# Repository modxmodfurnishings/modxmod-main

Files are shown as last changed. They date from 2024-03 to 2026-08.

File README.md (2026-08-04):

# MODxMOD Main Project

## Rationale

Furniture and devices should adapt to people, not the other way around.

MODxMOD FURNISHINGS strives to create an open system (the Open Furnishings System) of integration between hardware-to-hardware components, as well as hardware-to-software and software-to-software components.  As an organization, we will provide these components and specifications, but the open source nature of this project allows anyone to build upon and adapt the technology and plans to their personal needs.

In short: everyone can be a creator, everyone can interoperate, and no one organization will own the interoperation technology.

See the in-depth [rationale explanation](./docs/rationale.md).

## System Parts

The Open Furnishings System describes several pieces:

- Naming and templates for parts
- Naming and templates interfaces
- Naming and workflows for interactions
- Templates for various solutions

## Designs that change

Designs in this repository are subject to change, especially those in the Labs folder.

## License

modxmod-main by MODxMOD FURNISHINGS is marked with CC0 1.0.
To view a copy of this license, visit http://creativecommons.org/publicdomain/zero/1.0

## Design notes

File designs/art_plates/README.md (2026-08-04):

# Art Plates

User-swappable exterior art is one of the core goals of MODxMOD FURNISHINGS products. Different specifications ensure the best fit for your art pieces. This document describes art plates compatible with the [Mod Block](../mod_block/).

Our goal is to encourage user-created art, so here are specifications for making your own! See some cool [examples](#examples) below.

## How to use this document

This document provides details on terminology and dimensional specifications. It will also point you to resources. Most units are in metric, and Imperial equivalents are shown where possible. ***Note: Imperial units may be rounded down to the nearest fraction.***

## Quick start

The fastest way to start is to:

- 3D print using the `.STEP` file, or
- Laser cut using the `.DXF` file

Be sure to use one 1/4" material or two 1/8" materials.

## AP102 (Version 1.0)

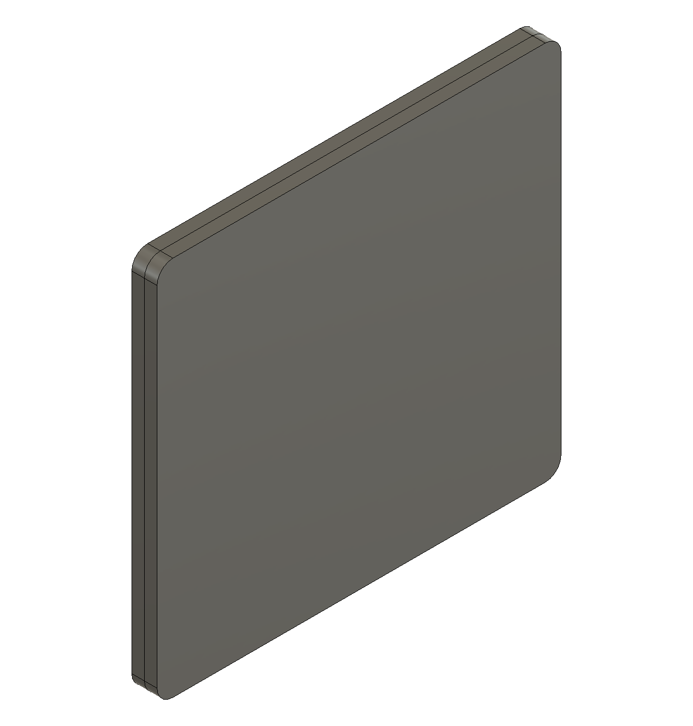
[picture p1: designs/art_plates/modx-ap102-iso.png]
AP102 isometric drawing


Starting with the [Mod Block](../mod_block/) product, you can create front art plates that slide into the provided slots. In general, your design should be slightly smaller than a 4" coaster.

### Viewable area

Because the art plates rest inside a 6mm-deep slot, the visible area is actually 90x90mm (3.5x3.5").

It is also best to leave a bit of padding around the design, perhaps 10mm (3/8").

### Maximum Dimensions

The maximum dimensions are:

- 102mm wide, 102mm tall, 6.5mm thick
- 4" wide, 4" tall, 1/4" thick

The slot it fits into is machined to:

- 103mm wide, 103mm tall, 7mm deep

You *must allow* for a small amount of wiggle room, hence the *102mm maximum dimension*:

- Wood may change shape
- The plates must slide in/out easily, and
- There are machining inconsistencies

The thickness is designed to easily accommodate one 1/4" sheet of plywood or two 1/8" sheets of plywood. Laser-safe acrylic often comes in similar thicknesses.

The 102x102mm dimension is also approximately the same as a standard 4" coaster.

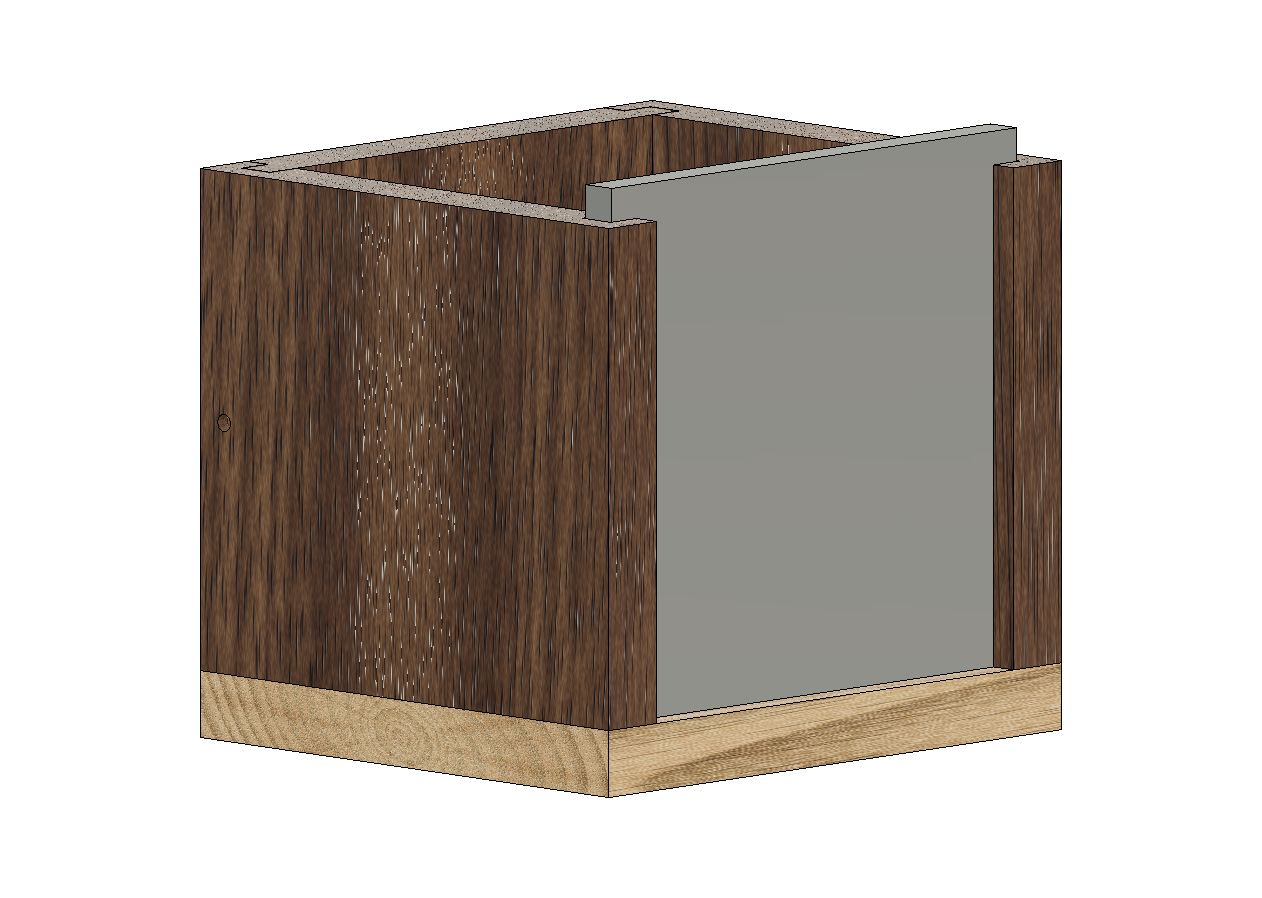
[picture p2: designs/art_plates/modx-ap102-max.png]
Drawing of art plate exceeding the top of the Mod Block


If you create the maximum 102x102 size, it ***will*** protrude over the top of the [Mod Block](../mod_block/). This is fine because the box's cap has a recessed slot. However, for designs meant to be used without the box cap, you should use the "short" height.

### Short Dimensions

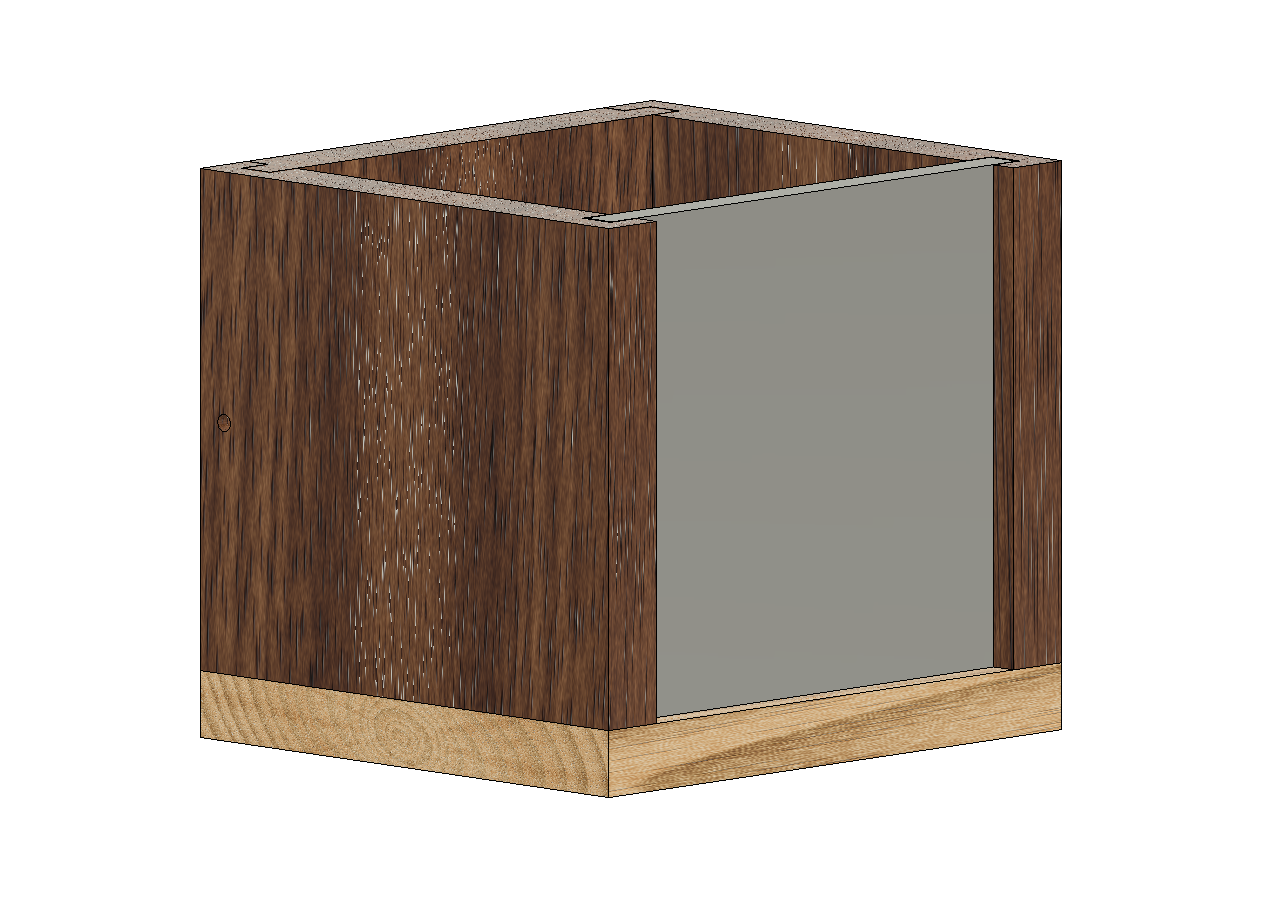
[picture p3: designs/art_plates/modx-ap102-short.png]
Drawing of art plate exceeding the top of the Mod Block


The recommended dimensions for open-box designs are:

- 102mm wide, 96mm tall, 6.5mm thick
- 4" wide, 3.75" tall, 1/4" thick

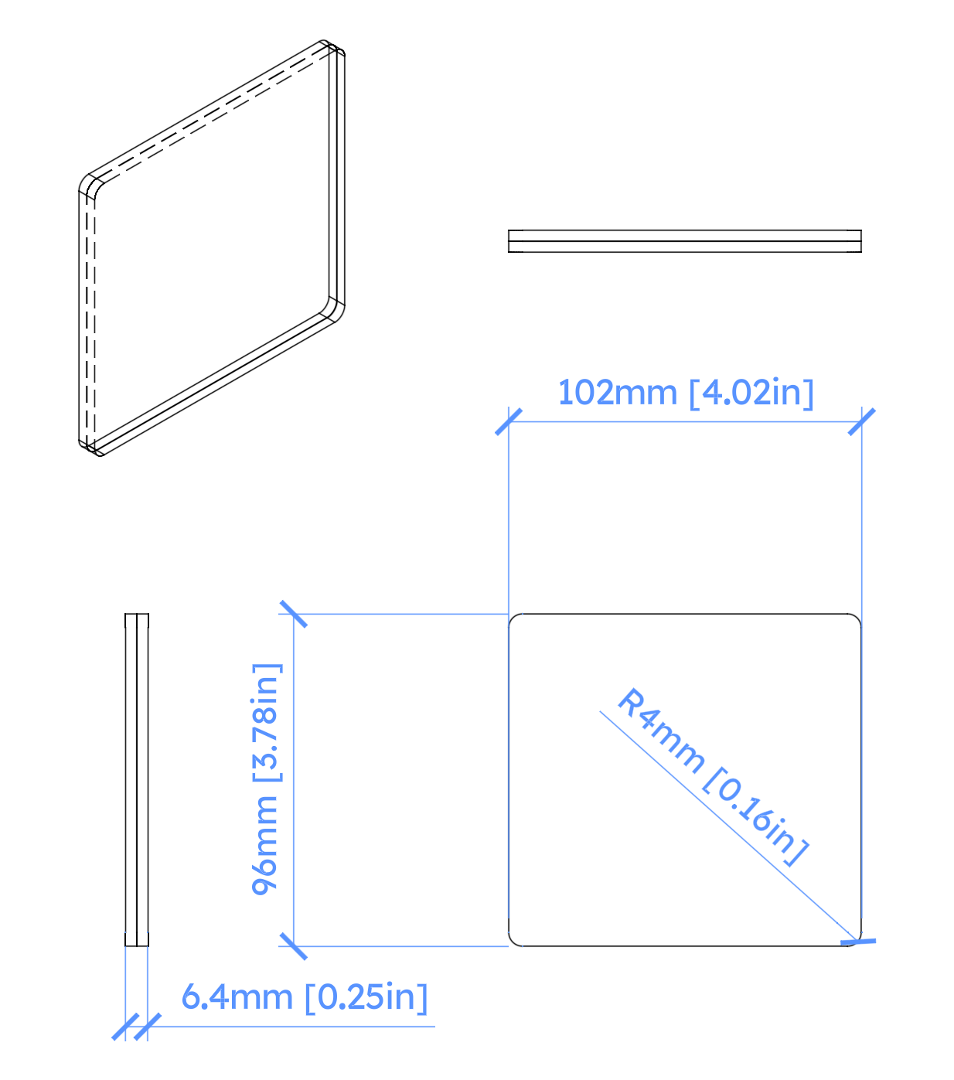
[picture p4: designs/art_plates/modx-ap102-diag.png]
Diagram of AP102 short


### Recommendations

- **Round off the corners about 4mm.** The slots the art plates sit in may not be perfectly machined.
- **Use calipers.** Ensure the total thickness of the materials doesn't exceed 6.5mm.
- **Use quality materials.** Ensure the materials are clean and smooth. Plywood is very stable. 3D prints are stable if the bed adhesion was good.
- **Create centered short designs:**
  - First design for the maximum 102x102mm dimension
  - Remove the top 6mm of the design, leaving 102x96mm
- The viewable area of the installed art plate is 90x90mm (3.5x3.5"):
  - Repeating patterns should extend the full 102x96mm so they disappear into the slots.
  - Centered designs look best when they have some visual padding. The recommended centered design in the art plate is 74x74mm (2-7/8" square).

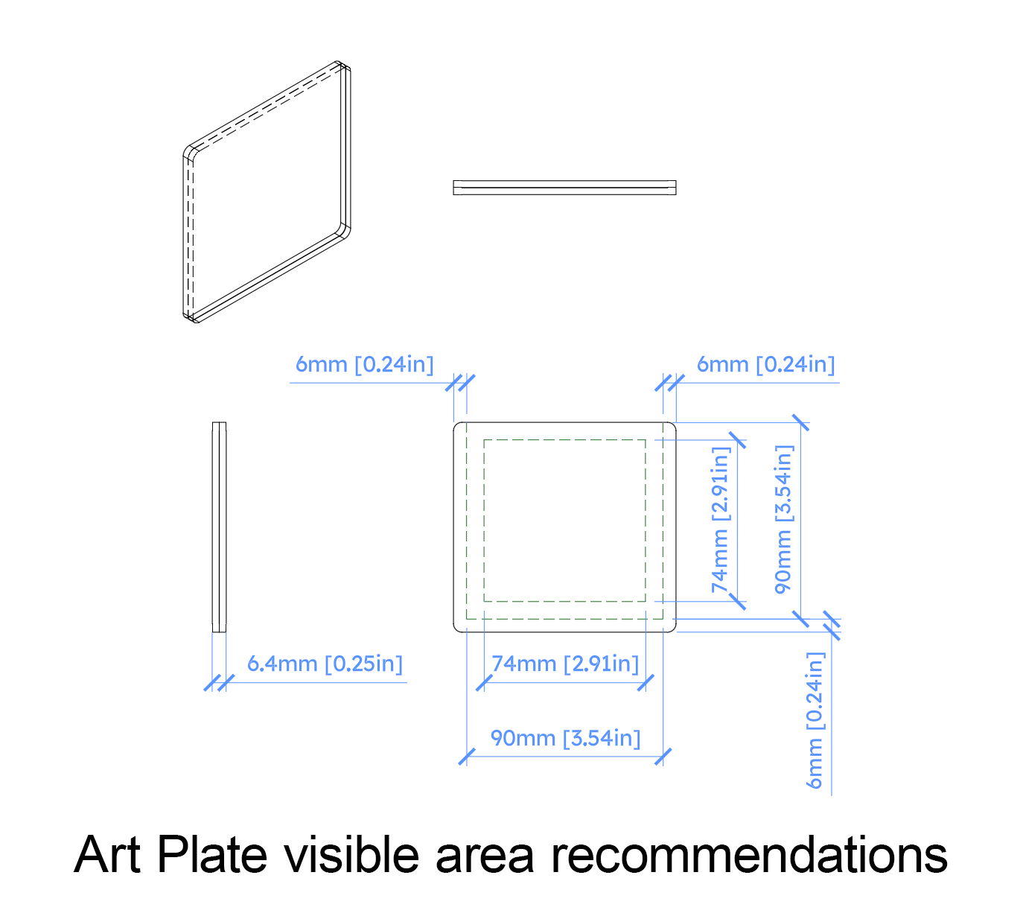
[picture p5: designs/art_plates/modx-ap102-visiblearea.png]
Diagram of recommended visible area


## Examples

### Solid front example

Use the `AP102-14inch.step` or `modx-ap102-short.dxf` files to cut out 1/4" material (or two 1/8" materials).

### Semi-open design example

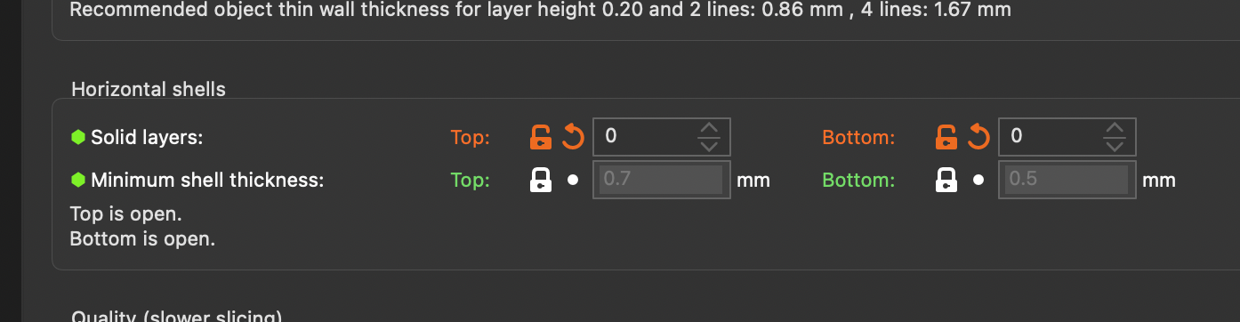
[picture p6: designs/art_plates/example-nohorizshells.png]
Screen shot of slicer configuration


In your 3D printer slicer software, import the `.STEP` model and ***don't print*** the top and bottom "horizontal shells". This will expose the infill pattern, and you can get some very nice effects.

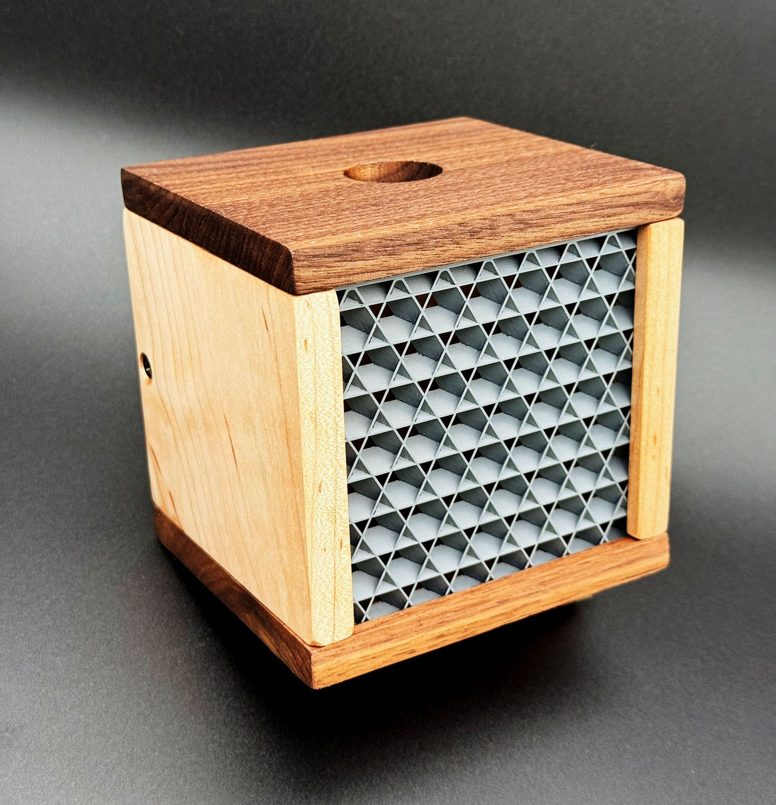
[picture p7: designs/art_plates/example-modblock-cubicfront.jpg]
Photo of 3D printed art plate


### Offset layered design

By cutting two 1/8" plates where the rear plate has slightly smaller holes, you get a layered dimensional design:

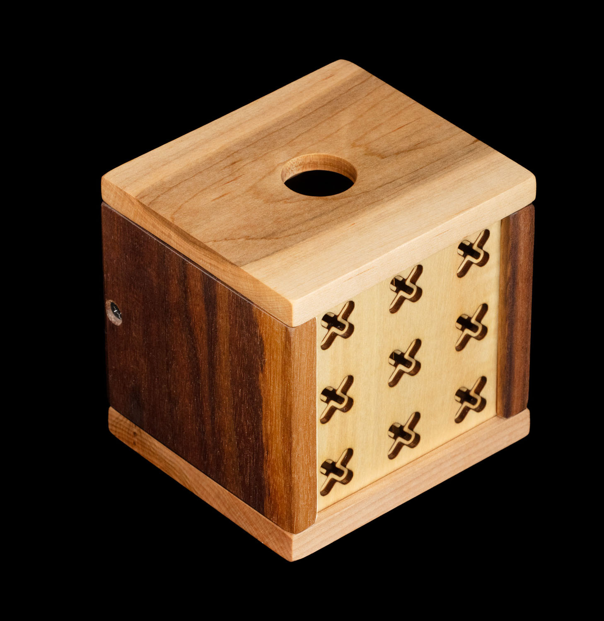
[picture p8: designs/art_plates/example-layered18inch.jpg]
Photo of two layered art plates


## Resources

- [Art Plate models](./models/)
- [Mod Block models](../mod_block/models/)

## Copyright and license

This file and all other files in this repository are marked with CC0 1.0. To view a copy of this license, visit http://creativecommons.org/publicdomain/zero/1.0

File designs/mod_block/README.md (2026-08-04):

# Mod Block

Mod Block with X Marks design front

The Mod Block is intended to be a transformable container. The main features:

- Footprint is 114mm wide by 102mm deep (4.5" wide x 4" deep)
- 12mm thick walls
- Screws-only assembly, no glued walls, no unfinished surfaces
- Symmetric wall 6mm-deep 7mm-wide slots, floor and lid 6mm-deep slots (1/4"), fits a standard 4" coaster
- Standard 1" rear hole, shipped with a 1" press fit 3D printed plug
- 90x90mm viewable area (3.5x3.5")

In the current shipping state as of July 2026:

- Floor secures the walls with screws
- Rear wall screwed in
- Press fit lid with 8mm interior protrusion, 1" finger hole
- User-swappable front plates

## Dimensions with lid on

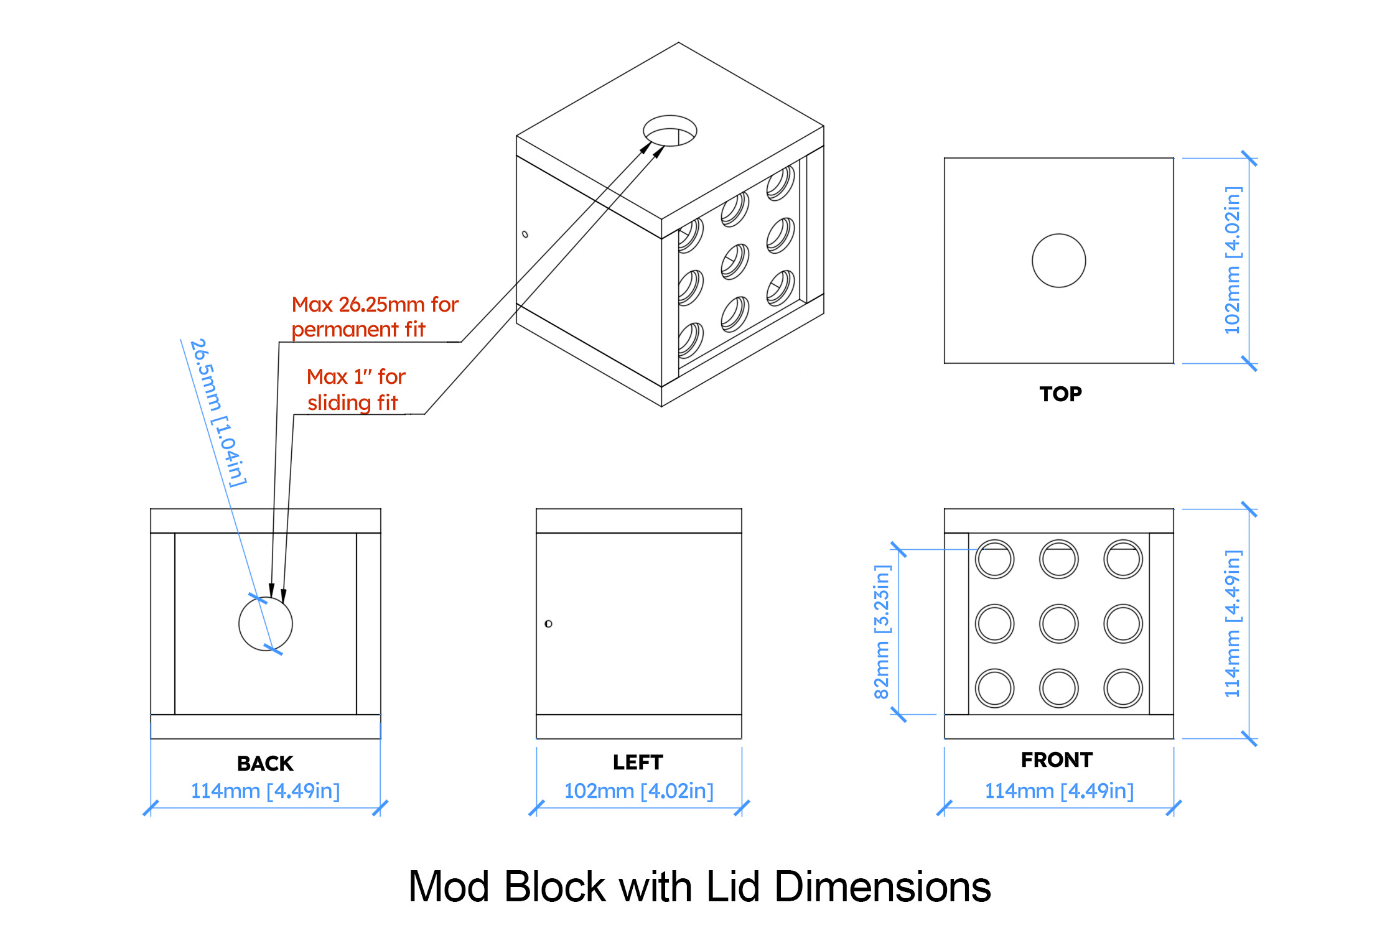
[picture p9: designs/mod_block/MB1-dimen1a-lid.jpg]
Diagram of Mod Block with lid


The current version with lid on measures:

- 114mm wide, 102mm deep, 114mm tall
- 4.5" wide, 4" deep, 4.5" tall

When the front is viewed straight-on, it looks like a square block with a 90mm x 90mm design area (3.5" x 3.5"). The front panel can be swapped with different designs or removed for open access.

*Note: The press fit lid reduces the inner height by 8mm; you should consider 2mm extra padding.*

The effective interior volume is:

- 90mm wide x 78mm deep x 80mm tall
- 3.5" wide x 3" deep x 3.125" tall

## Dimensions with lid off

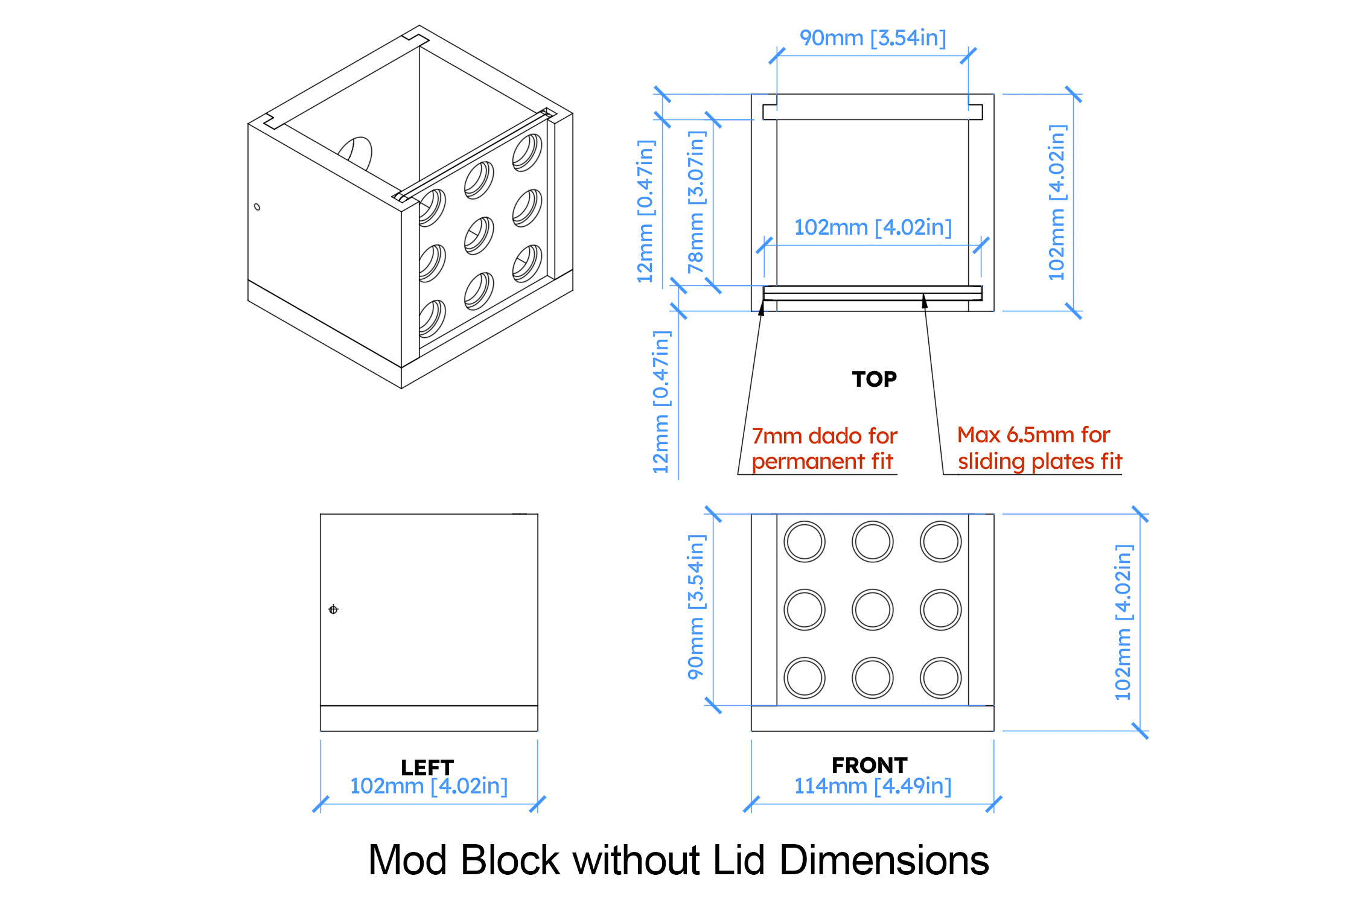
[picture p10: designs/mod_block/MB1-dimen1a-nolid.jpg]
Diagram of Mod Block without lid


With the lid off, the Mod Block is 12mm shorter:

- 114mm wide, 102mm deep, 102mm tall
- 4.5" wide, 4" deep, 4.5" tall

But the interior volume is greater:

- 90mm wide x 78mm deep x 90mm tall
- 3.5" wide x 3" deep x 3.5" tall

*If you remove the front art plate, the interior volume can accomodate a 3.5" notepad cube.*

## Rear/top hole Mod Plug

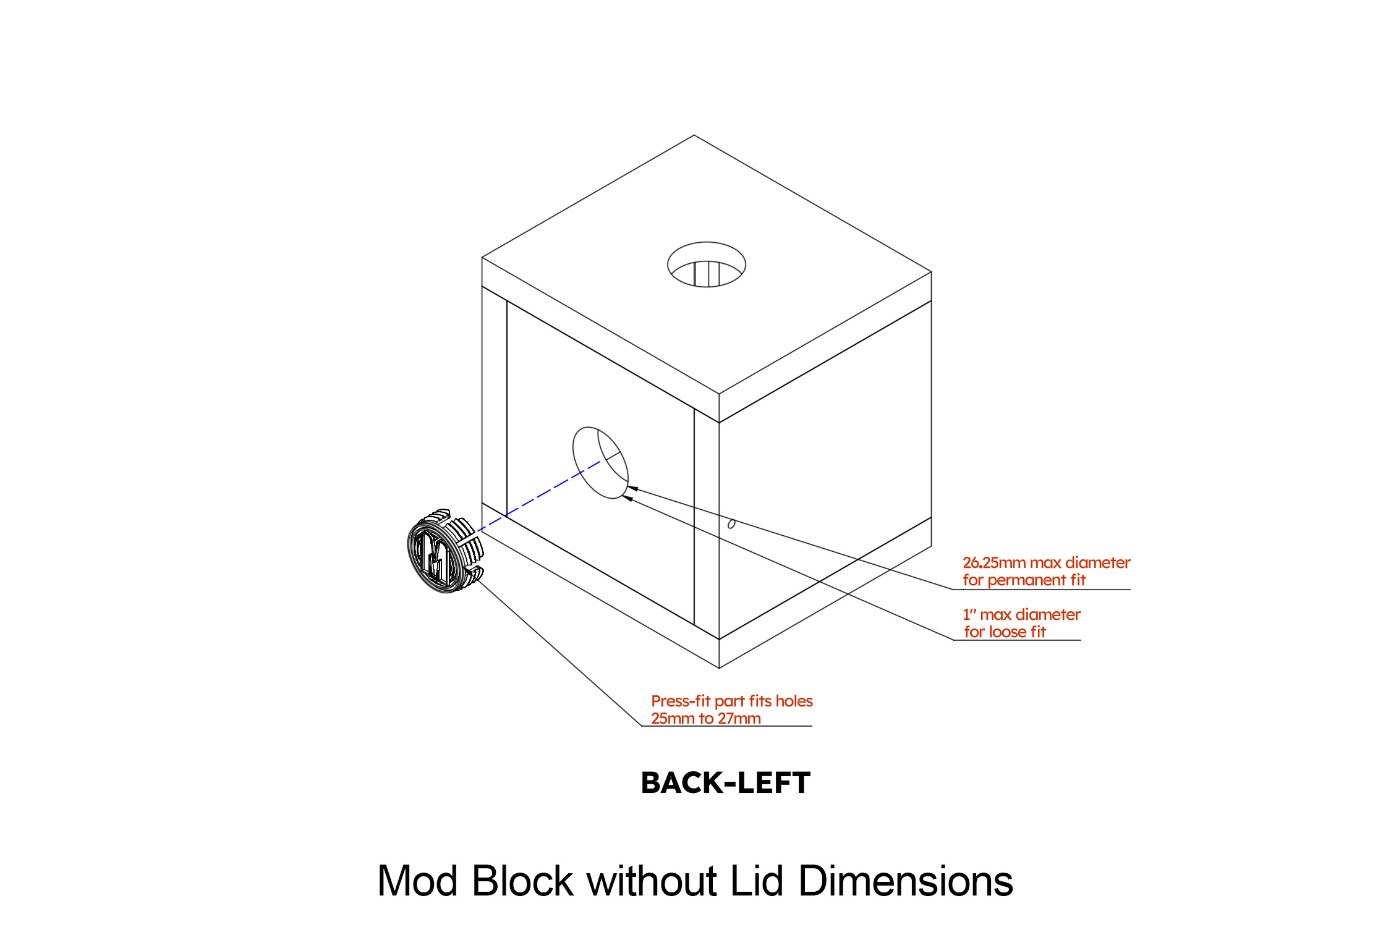
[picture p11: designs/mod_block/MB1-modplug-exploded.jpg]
Mod Plug location diagram


The shipping Mod Block has two 1" openings (machined to 26.5mm), the rear hole is covered with a Mod Plug. The rear hole may change diameter slightly over time due to humidity and material changes.

The Mod Plug or another accessory should adhere to these two diameters:

- 25.4mm (1") for a loose fit. Perfect for dowels or rotating parts.
- 26.25mm for a permanent fit. These parts will likely become difficult to remove; in very dry weather this may become a loose fit.
- 10.5mm is optimal thickness

The shipping Mod Plug has flexible arms which allow it to accommodate holes from 25mm to 27mm. See the [mod_plug](../mod_plug/README.md) directory for specifications.

Permanent installation of a part in the rear or top hole should be done with screws and/or glue. This is especially important if it will be modified.

The Mod Plug design also permits 1/8" material to be slotted into it. See the next section.

## Removable divider panels

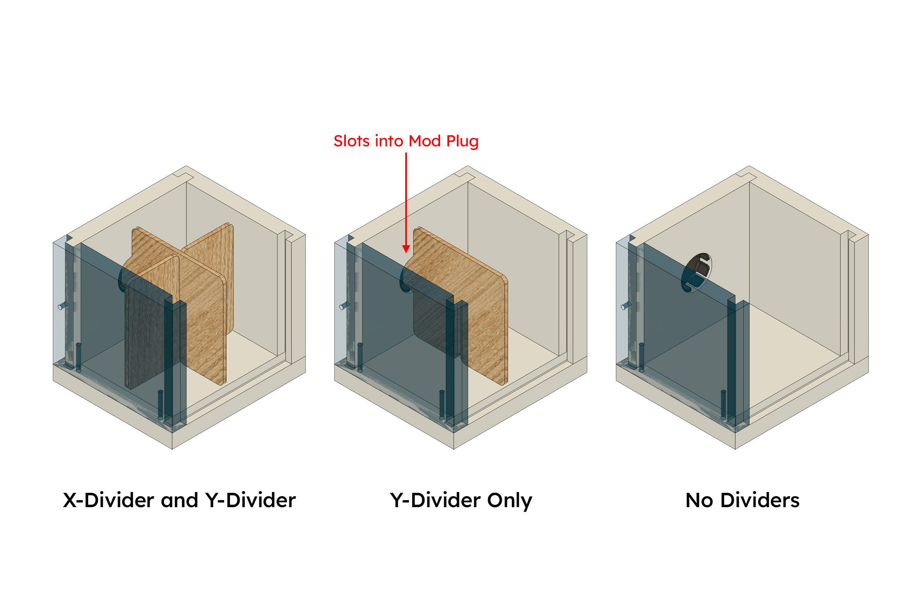
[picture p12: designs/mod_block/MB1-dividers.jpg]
Removable internal dividers diagram


The Mod Block ships with 1/8" dividers that have an interlocking slot in their center. The Y-Divider (that goes from front to back) and an X-Divider (that goes from left to right). The Y-Divider has a key that fits into the Mod Plug in the rear wall to keep it vertically aligned. This configuration creates 4 chambers in the Mod Block.

By removing the X-Divider, the Mod Block has 2 chambers. And by removing all of the dividers it is an open box.

You can design new dividers or inserts. The recommended material is 1/8" thick (approximately 3mm thick) because that will fit into the Mod Plug. But you could design new shapes and even a new Mod Plug (or no plug) as it suits your design goals.

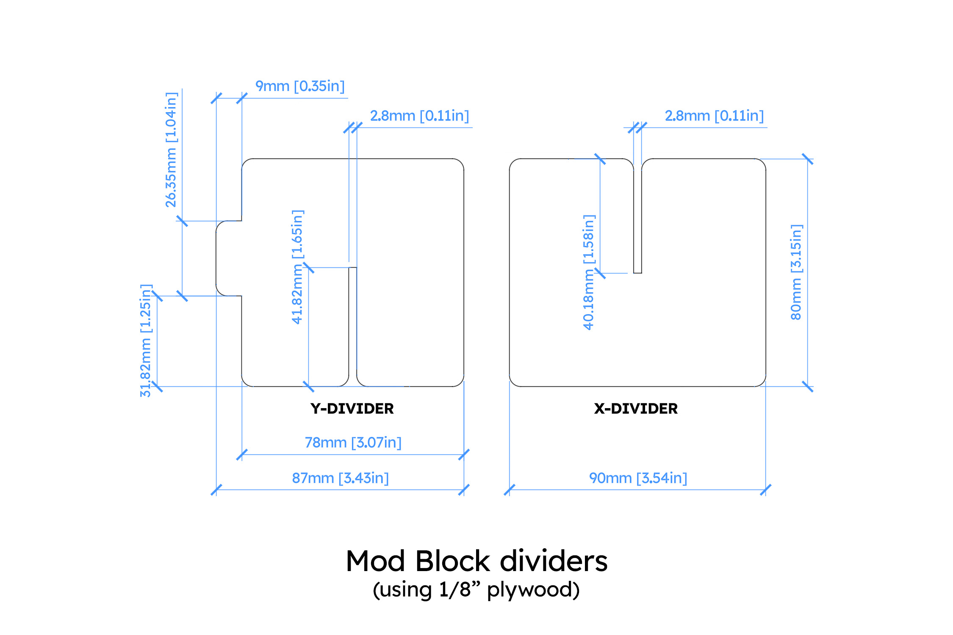
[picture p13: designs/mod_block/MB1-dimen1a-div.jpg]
Diagram of the Y-Divider and X-Divider


## Swappable Art Plates

The front 7mm slots are identical to the rear 7mm slots. In the shipping Mod Block, the front slots have a user-changeable design. 

For more details, please see the [Art Plates](../art_plates/) documentation.

## Resources

- [Mod Block models](./models/)
- [Art Plate models](../art_plates/models/)

## Copyright and license

This file and all other files in this repository are marked with CC0 1.0. To view a copy of this license, visit http://creativecommons.org/publicdomain/zero/1.0

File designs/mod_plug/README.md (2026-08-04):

# Mod Plug

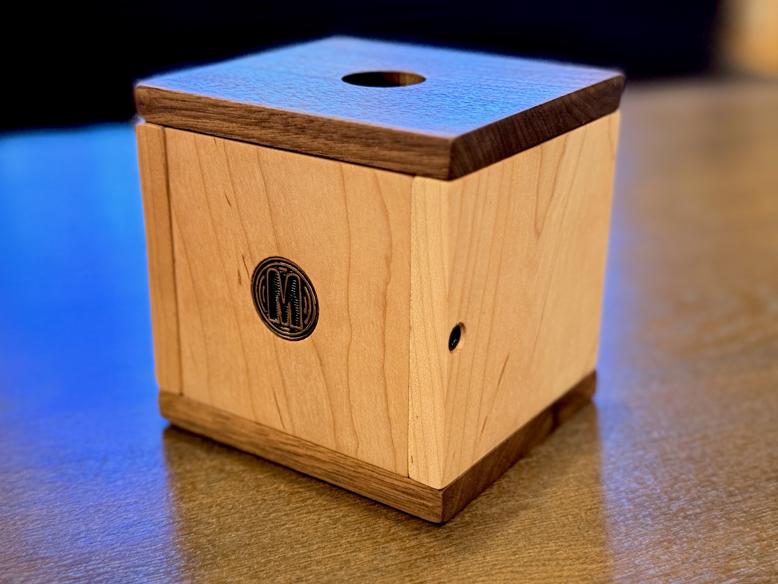
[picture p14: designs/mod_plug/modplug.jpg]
Mod Plug with gold logo, installed


The Mod Plug is a press fit part designed to block the rear hole in a [Mod Block](../mod_block/README.md). It can be permanently installed if desired.

## Mod Plug specifications

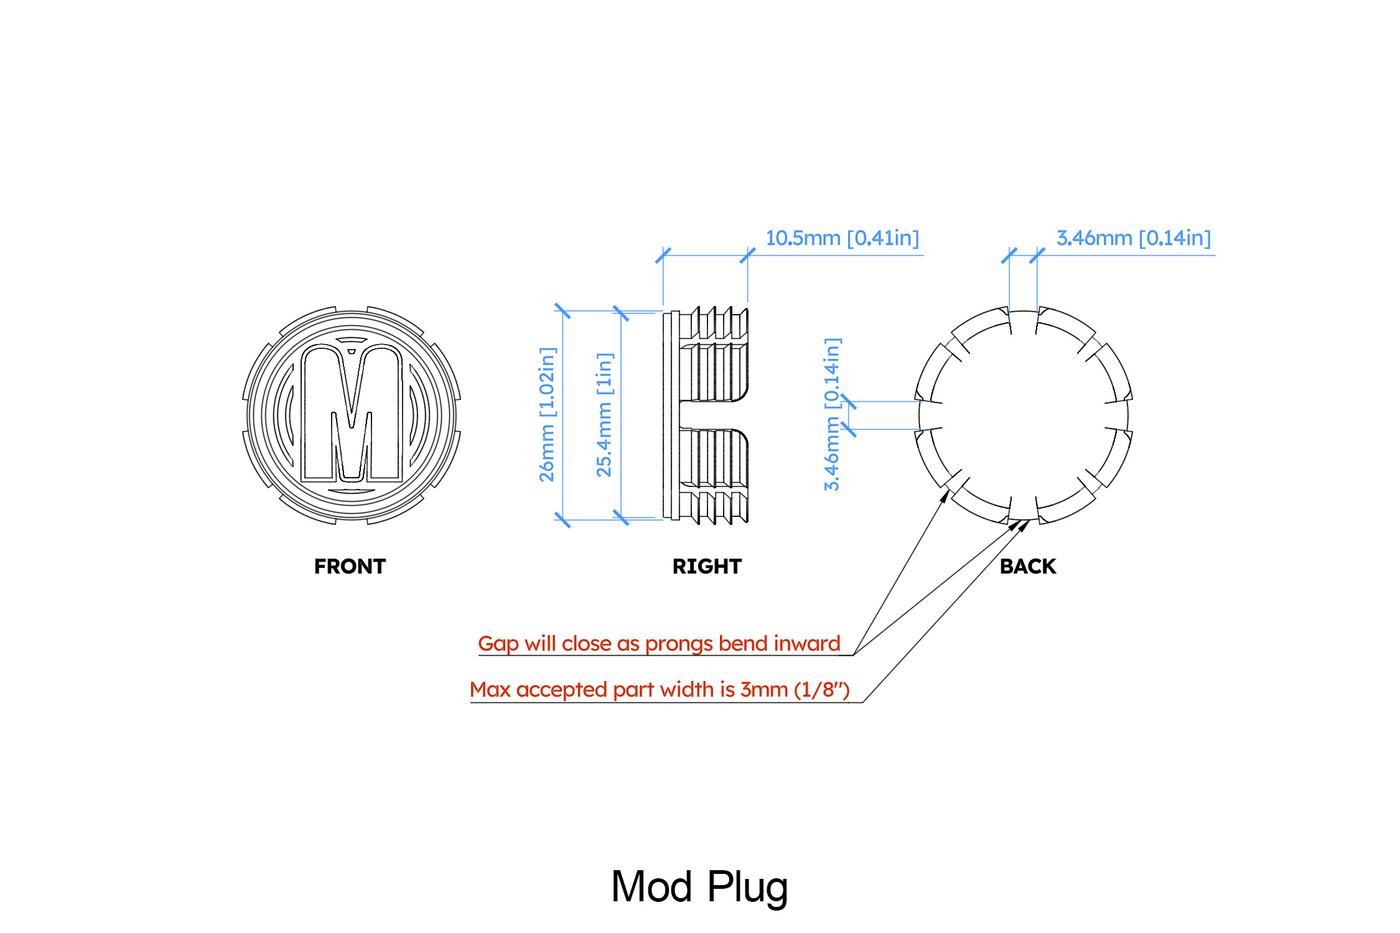
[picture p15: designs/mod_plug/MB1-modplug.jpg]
Diagram of Mod Plug


The provided Mod Plug is a 3D printed part which has flexible arms that should accommodate hole sizes from 25.0mm to 27.0mm. To permanently secure the Mod Plug you should use an adhesive such as epoxy glue or screw the plug into the back wall material.

- No support material required
- PTEG or ABS filament will be stronger, PLA will be more flexible
- Production part uses 0.4mm extruder nozzle
- First bed layers should be 0.5mm, print "logo side" down on bed

## Copyright and license

This file and all other files in this repository are marked with CC0 1.0. To view a copy of this license, visit http://creativecommons.org/publicdomain/zero/1.0

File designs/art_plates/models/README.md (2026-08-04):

# Art Plates models

The purpose of supplying these models is to assist in providing reference assemblies. They are exported in two different formats:

- `.step` meshes exported directly from CAD, and
- `.stl` models processed through a slicer

See also the [Mod Block models](../../mod_block/models/README.md).

## Rationale

By providing models of the 102x96mm Art Plates, artists can install their own designs into Mod Blocks. Product designers may also adapt Art Plates to provide interesting apertures or devices.

As discussed in the [Art Plates README](../README.md), 102mm is effectively a 4" width which is common in square coasters. The 96mm height is preferred because with the box cap removed the top of the art will sit flush with the top edge of the Mod Block.

You may simply design using 4" square coasters, realizing a small top portion of the design will be tucked into the cap.

## File descriptions

The main source files are:

| Filename | Type | Description |
|---|---|---|
| AP102-14inch.step | STEP | Assembled Art Plates as one 1/4" part. |

These have been converted into flattened models:

| Filename | Type | Description |
|---|---|---|
| AP102-14inch.stl | STL  | Assembled 1/4" Art Plate. |
| AP102-2x18inch.stl | STL  | Separated 1/8" Art Plates in 2 parts. |

## Recommended use

### 3D printed Art Plates

3D printing is one of the easiest ways to produce the Art Plates.

Printing a full 1/4" plate will allow you to create some interesting fill patterns. See the [Art Plate examples](../README.md).

### CNC milled Art Plates

It is possible to mill out a relief design. The edges of your Art Plate should be no thicker than 6.5mm, meaning the central part of your design could project forward beyond the front of the Mod Block when installed.

Also, you may desire to mill a 6mm solid wood canvas instead so you can paint on it. The built-up paint will likely add up to 0.5mm thickness. *Note: consider reducing the size of the Art Plate to 101mm on the long dimension in case paint runs over the edges.*

### Laser cut Art Plates

Laser cutting is one of the most efficient ways to make Art Plates. In fact, the production Mod Blocks ship with two 1/8" laser-cut plywood designs. 

## Copyright and license

This file and all other files in this repository are marked with CC0 1.0. To view a copy of this license, visit http://creativecommons.org/publicdomain/zero/1.0

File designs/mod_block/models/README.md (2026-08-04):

# Mod Block models

The purpose of supplying these models is to assist in providing reference assemblies. They are exported in two different formats:

- `.step` meshes exported directly from CAD, and
- `.stl` models processed through a slicer

See also the [Art Plates models](../../art_plates/models/README.md).

## Rationale

By providing these models, you can construct your Mod Block out of various materials. No specific 3D printer or CNC router is specified, so that you can adapt it to your own equipment.

We hope that you can create fixtures and shelving to hold Mod Blocks, and also create custom solutions that fit the Mod Block's specifications. Tell us about your creations via social media or email: [https://www.modxmod.com/pages/contact](https://www.modxmod.com/pages/contact)

## File descriptions

The main source files are:

| Filename | Type | Description |
|---|---|---|
| MB1-body.step | STEP | The assembled main Mod Block body in 4 parts. |
| MB1-cap.step | STEP | Only the press fit cap. |

These have been converted into flattened models:

| Filename | Type | Description |
|---|---|---|
| MB1-1body.stl | STL  | The assembled main Mod Block body as 1 part. |
| MB1-multibody.stl  | STL  | Disassembled 4 parts of the Mod Block body.  |
| MB1-cap.stl | STL  | Only the press fit cap. |

## Recommended use

### 3D Printing

3D printing is one of the easiest ways to produce a Mod Block, and you have two primary choices:

- Print the body as one whole part: `MB1-1body.stl`
  - This does not require any fasteners
- Print the separated parts: `MB1-multibody.stl`
  - You may have to print only 1 or 2 bodies at a time depending on the size of your build platform
  - You will have to adjust the model to accommodate your screws and other fasteners (or glue it together)
    - We recommend M3 cap head screws
    - Print the floor screw shafts vertically
    - The wall screw shafts are OK printed sideways:
      - The filament will create a slightly smaller hole than the M3
      - As you twist the screw in, it should cut threads into the filament
    - You may need to adjust the depth of your wall screw shafts to accommodate your desired screw length

### CNC routing

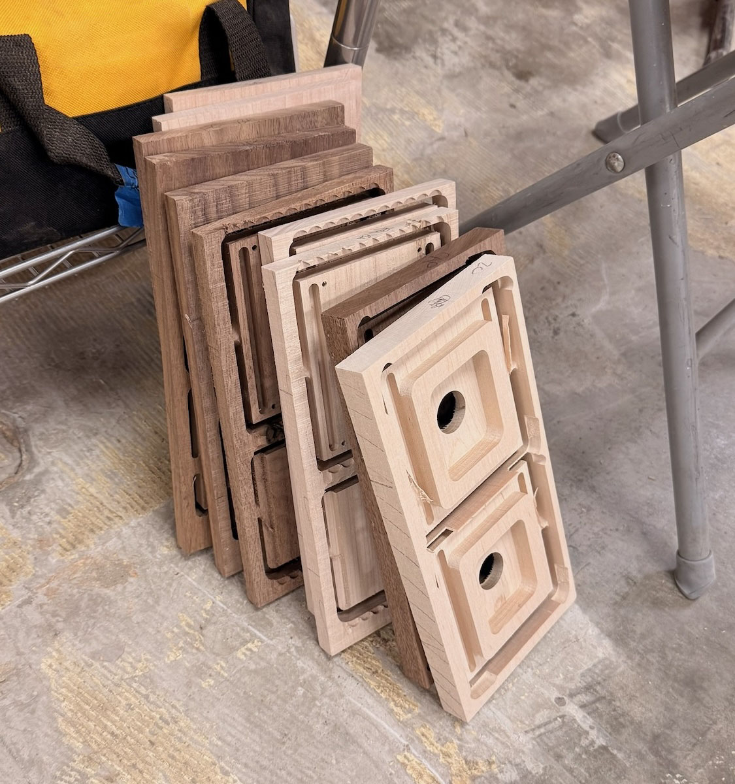
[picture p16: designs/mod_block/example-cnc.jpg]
CNC machined wood slabs


#### Machining tips

Recommended bits:

- 1/4" spiral downcut or 1/4" compression
- 1/8" spiral upcut

The production Mod Block boxes are CNC routed mostly using a 1/4" bit, except for the pilot holes, which are drilled with an 1/8" bit. Tabs are placed along the long edges.

The floor and walls are milled from 12mm stock. The press fit caps are milled from 20mm stock.

We recommend machining with the Z-origin as the machine bed. One of the first operations you can do on the material is a surfacing pass to reduce its thickness to either 12mm or 20mm. (In production, we use S3S 5/4 resawn to 14mm slabs then surfaced to 12mm; and 20.5mm S3S slabs left unsurfaced because they're close enough to 20mm). It is OK if the thickness is slightly thicker than the recommended 12mm and 20mm.

The reason G-code is not provided is that every machine varies and your cuts may be material-dependent.

#### Assembly and finishing tips

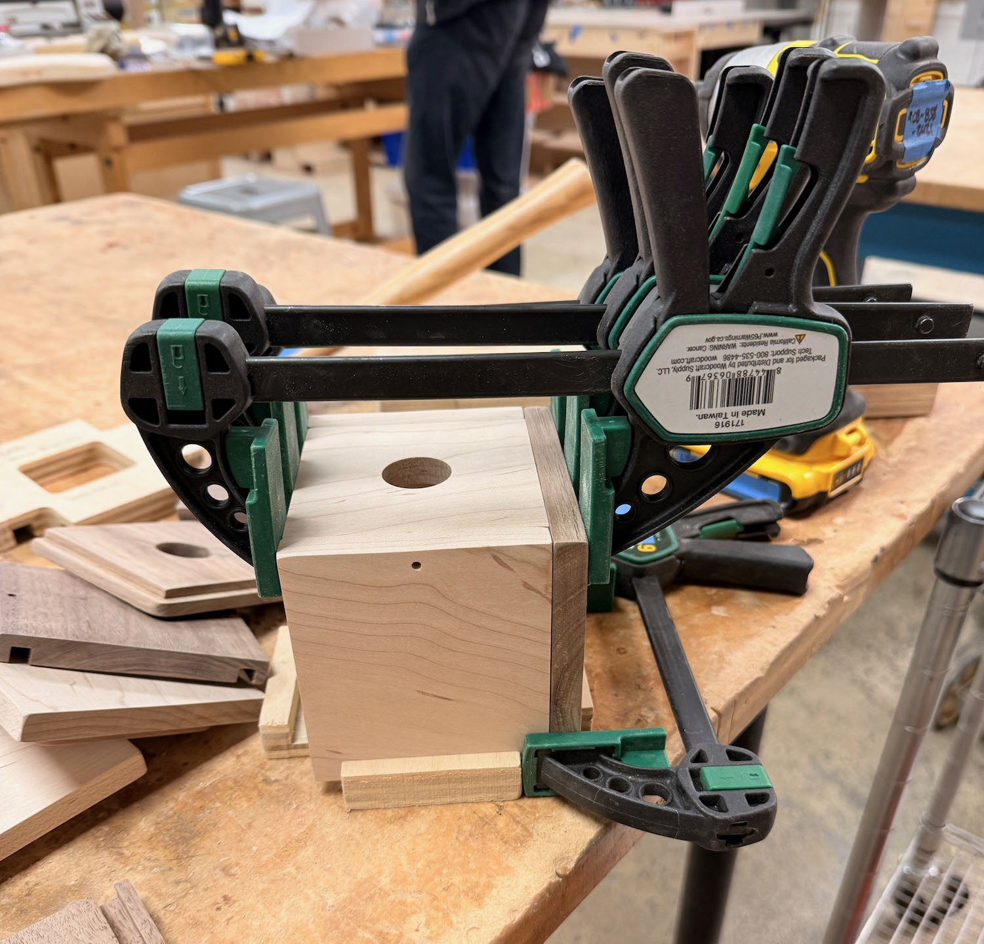
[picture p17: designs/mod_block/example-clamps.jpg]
Clamped Mod Block floor and walls


There are 4 screw holes in the floor and 2 screw holes in the walls. We recommend:

- Do a moderate amount of sanding and grain raising before sanding to ensure good fit
- Clamp the walls and floor together as one assembly and align the parts
- Use a counterbore hole drilling bit (e.g., search for "1/8 x 3/8 Countersink bit"), and drill far enough that the screw head is *just below* the surface (instead of sitting even with the surface)
- Twist by hand 1" #6 wood screws (or anything that fits the 1/8" diameter holes) into the countersunk holes
- After boring the holes and fitting the screws, disassemble and do final sanding and finishing as desired

This order of operations should give you a better-fitting box.

## To glue or not to glue?

The production Mod Blocks are fastened without glue so the walls can be disassembled for repair or for customization.

To create a permanent Mod Block, you certainly can glue the parts together. You may wish to eliminate the screw holes, or use small dowels in the holes for strength.

## Copyright and license

This file and all other files in this repository are marked with CC0 1.0. To view a copy of this license, visit http://creativecommons.org/publicdomain/zero/1.0

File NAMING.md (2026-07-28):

# Naming of Things

The Open Furniture System (OFS) needs a standard set of language to ensure interoperability.

## Nouns

### Accessory

A product which is designed to support the functionality of another product, or a product with limited functionality. Hooks and shelves can be accessories, trays and stands can be accessories. Tools may also be accessories.

### Assembly

Two or more parts joined together in some fashion so they function as a whole. A sufficiently complex assembly may be considered a component. An assembly can be made up from sub-assemblies.

### Attachment Point

The physical location that can accept a connector. Holes and slots are attachment points.

### Bundle

A set of products and accessories sold as a single purchasable unit.

### Cabinet

A sturdy box designed for holding significant weight of items inside it. It is open on at least one side. A cabinet may have doors to temporarily seal the cabinet.

### Case

A box containing a product. A case can be simple (chipboard box, cardboard box) or more durable (wood case, metal case).

### Component

An assembly which performs a useful role in a product.

### Connector

A part of a specific shape that permits the joining of two products. The connector can be a product itself. The studs on a hanging panel that mate with an attachment point are connectors. A screw by itself is generally not a connector because it is a part in a kit.

### Fastener

Simple parts that hold two materials together or join products. Screws and locking cams are popular fasteners. Fasteners are generally not considered connectors because they are not sold individually. Washers on fasteners are not considered to be part of the fastener.

The advantage of fasteners is that assembled parts can be disassembled.

### Glue

An adhesive product that permanently locks two or more parts together. Glued parts are not generally designed to be separated. 

### Kit

A set of parts and components which are not fully assembled to create the full product, or a set of parts that support the construction of the product. A product may come partially disassebled as a kit to enable easier shipping, or a set of fasteners may be included with a product as a kit.

### Package

A shippable box containing a product, a kit, a bundle. To protect the interior contents, all items may be in a case.

### Part

Any single item or set of items used to make larger assemblies and components. A screw is a part, a bracket is a part, a software module is a part. Parts have defined boundaries; data and designs do not generally have boundaries. Parts are more than raw materials.

### Press fit

A part that is seated into another part merely by pushing it in, usually without the need of special tools. Some force may be required to insert the part. Once seated, the part may become temporarily or permanently attached.

### Sliding fit

A part is inserted into another by means of sliding it in, usually into guiding slots. Little or no effort should be needed to slide the part in; if force is required then it may be considered a press fit.

### Product

The primary thing that a user purchases that has useful functionality that a user buys. A drawer front is a product, a cabinet is a product, a soft-close door is a product, a software app is a product.

### Raw Material

The basic materials such as wood, metal, paper, and plastic filament, that are not yet in the shape of a functional part.

### Shelf

A platform with a floor and optional walls that holds significant weight of items placed on it. A shelf is generally part of a product or it is an accessory if sold separately.

## Verbs and Actions

### Connect, Disconnect

"To connect" is to join two products or components together by means of a connector.

### Fasten

"To fasten" is to use fasteners to join two parts, two assemblies, two components, or two products together.

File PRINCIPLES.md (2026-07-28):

# Open Furninshings System Principles

The guiding principles of the Open Furshishings System (OFS) help to ensure decisions we all make are in alignment.

## How to use the Principles

Principles are listed in descending order of importantance: if there are two competing principles, the first principle should be valued more. However, exceptions may always be made to provide the best experience.

## Principle 1: People First

Solving for people's needs is primary goal. Any piece of furniture or the shape of an accessory can be modified to meet an individual's needs, even if it means less interoperability with other OFS Components.

## Principle 2: Compete on quality and artistry

OFS is primarily about common product sizes and attachment points where two products may connect. Creators and businesses are still able to create products with proprietary technology, copyright, and design patents. However, because the general specifications and attachment points are public domain, market competition is driven more on the quality of the products and the inspirational artistry in the design. Businesses should be encouraging interoperability even while making profits.

## Principle 3: Interoperability

Favor permitting connection between two products by using OFS attachment points and connectors, or using common dimensions. This empowers people to reconnect products and accessories to their needs.

## Principle 4: Simple products, complex solutions

Products should be relatively simple by themselves, but come together to solve complicated needs. For example, two medium cabinets, two smaller cabinets, and a tabletop provide a custom height desk for wheelchair-bound user.

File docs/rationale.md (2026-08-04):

# Rationale

Furniture and furnishings accessories are often permanent in our lives. We buy them once and treasure them. We covet "heirloom quality". But what happens when the circumstances of our lives change, or when we want to gift an item to someone else?

What often happens is these objects get thrown away into landfills. How might we prevent this waste? How do we enable repairability? How do we empower people to reconfigure the products they have? When we gift the products, how do the recipients suit their own taste?

This is why all MODxMOD FURNISHINGS products were designed with modularity in mind. Here's how we have attempted to achieve this:

- Create consistent naming of parts and attachment methods
- Use consistent sizes and placement of holes
- Use commonplace materials and widely available fasteners
- Provide open specifications and documentation
- Encourage people to modify and hack the products to their needs
- Separate the internal support structure from the outward facing veneers
- Create a community of others interested in building upon these modular systems
- Recognize that no product lasts forever and must be repaired

## Architecture vs. style

A house or an office building is a good metaphor for the Open Furnishings System (OFS):

- The structural members and room shapes are rarely changed
- The decorations and furniture in them continually change

Why can't we design furniture this way?

To enable multiple uses of the same piece of furniture, there needs to be a notion of which parts are the unchanging structure of the object versus the always-changing veneer.

In OFS, this is expressed with solid bases and rigid boxes that are fastened together to create larger structures. The dimensions of these architectural objects should be as consistent as possible.

## Creating the grid

We favor the metric system using multiples of 32mm:

- Most accessory trays are 256x128mm
- Most box units have face dimensions of 384x384mm and depths of 384mm or 512mm
- Holes that connect larger units are bored on a 128mm grid
- Holes that connect minor attachments are bored on a 32mm grid

Shelving pins and door hardware adhere to the 32mm system:

- Door hinges and cups
- Shelf pin placement
- Handles and pulls

However in North America many rods and knobs use Imperial measurements:

- 3/4", 1", and 1-1/2" wooden dowels
- 1" grommet caps

## Why CC0 and open source

The world is full of products that don't interoperate. To achieve widespread compatibility we have to focus on what matters: naming, sizes, and placement. What we don't need are legal and IP hurdles blocking innovation. This repository is a toolkit help spur your imagination and creativity.

By creating a Github repository we can create folders to group similar items together. We then store guides, templates, designs, and models in the folders. We can continually update this repository and you can subscribe to notifications. You can also propose contributions.

Creative Commons Zero is a way for us to ensure that no one can own the basic intellectual property of the system: the system isn't the important part, it's the products and the craftsmanship of each object. Let's focus on bringing more art, more usability, and more flexibility into our homes. 

CC0 does not prevent you from creating your own IP, patents, and designs that are derivative of this work. You should certainly be able to protect your unique products. However, you should not be able to claim the basic framework since all of us need to rely on OFS as a kind of shared utility.

## The future of OFS / how you can help

OFS is just beginning and has a lot of room to grow. We envision that there will be several bodies that govern:

- Naming, sizes, and interoperability specifications
- Prototyping and user testing
- Education and outreach, including documentation and training
- Managing a growing community with moderation and creating safe spaces for people to openly contribute and respectfully debate solutions
- Creating in-person events to let us celebrate our collaborative solutions and also show other people why OFS can benefit them

If you'd like to help, please reach out:[https://www.modxmod.com/pages/contact](https://www.modxmod.com/pages/contact)

Thanks.

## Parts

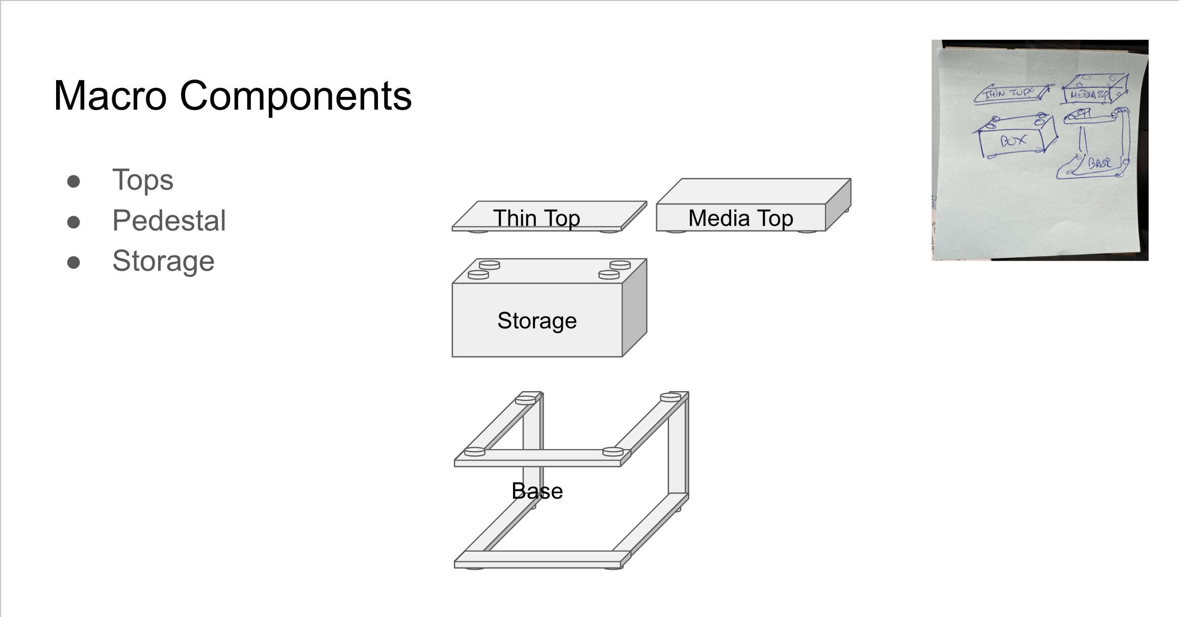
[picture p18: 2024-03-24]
labs/experimental/simple-template-20240324a-components.png

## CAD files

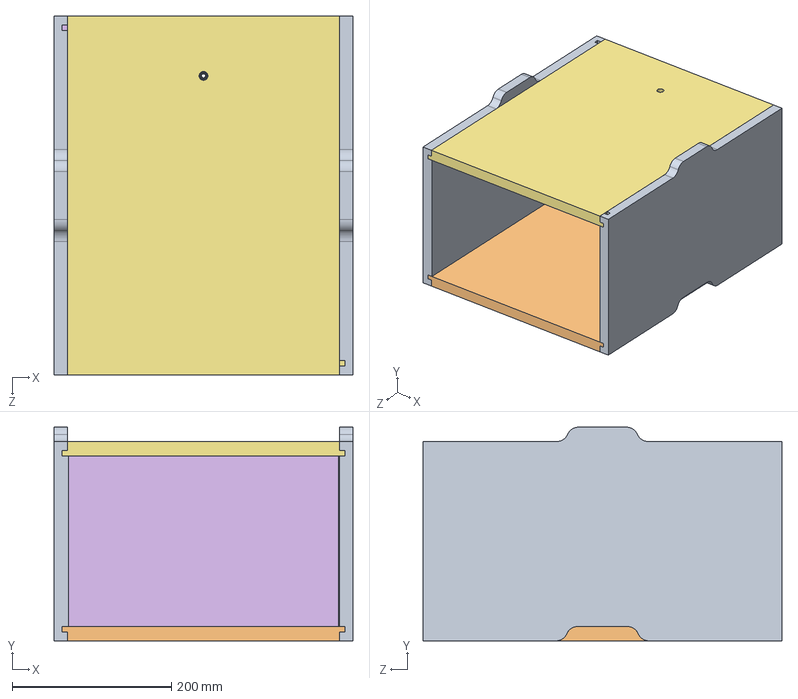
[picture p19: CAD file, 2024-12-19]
labs/experimental/F1125_box268_asm.STEP
375.0 x 268.0 x 450.0 mm
F1125_side268_left x 2
F1125_bot355
90266A346_316 Stainless Steel Easy-to-Install Thread-Locking Insert_90266A346
F1125_back230
F1125_top355

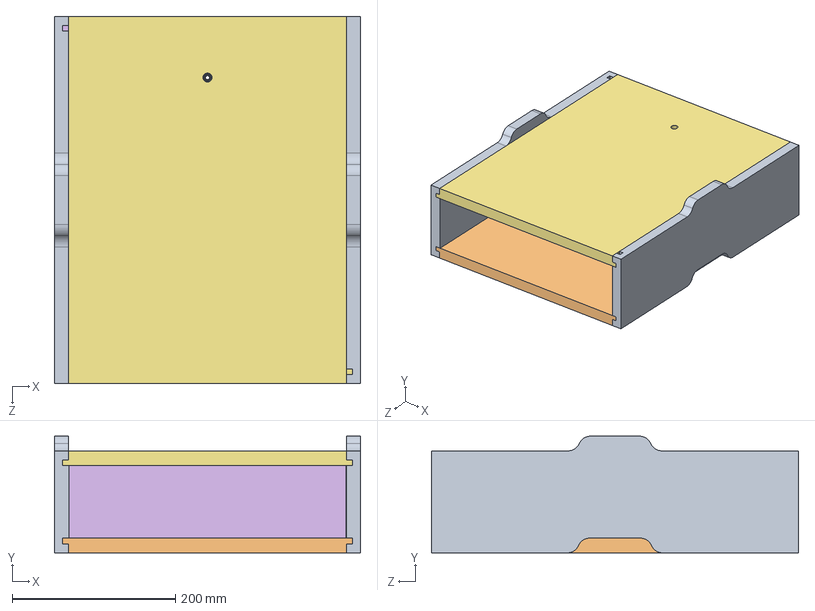
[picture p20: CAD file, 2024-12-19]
labs/experimental/F1125_box143_asm.STEP
375.0 x 143.0 x 450.0 mm
F1125_side143_left x 2
F1125_bot355
90266A346_316 Stainless Steel Easy-to-Install Thread-Locking Insert_90266A346
F1125_back105
F1125_top355

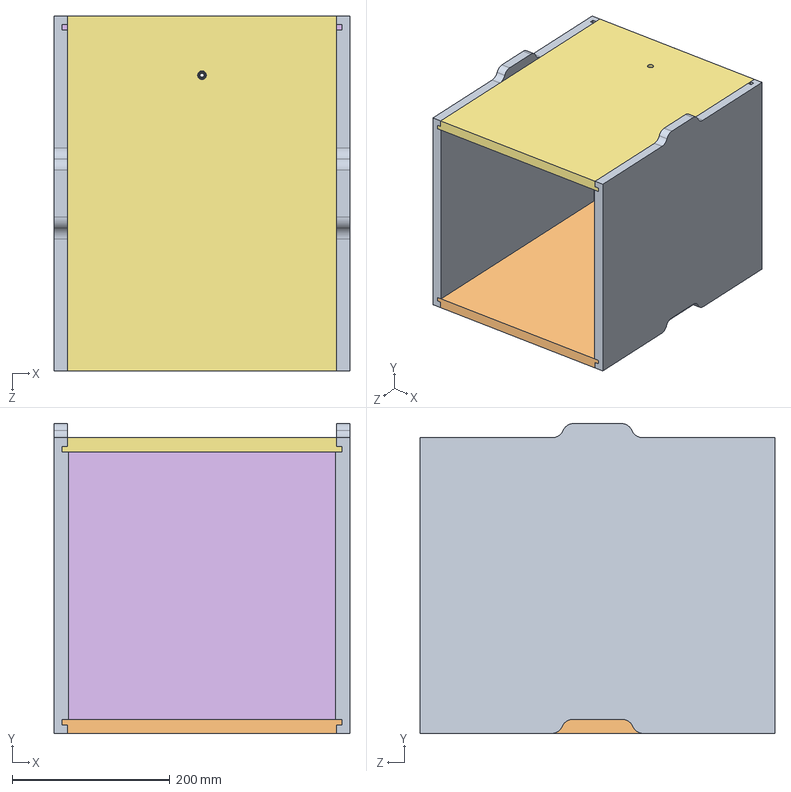
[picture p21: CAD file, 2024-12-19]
labs/experimental/F1125_box393_asm.STEP
375.0 x 393.0 x 450.0 mm
F1125_side393_left
MirrorF1125_side393_left
F1125_bot355
90266A346_316 Stainless Steel Easy-to-Install Thread-Locking Insert_90266A346
F1125_back355
F1125_top355

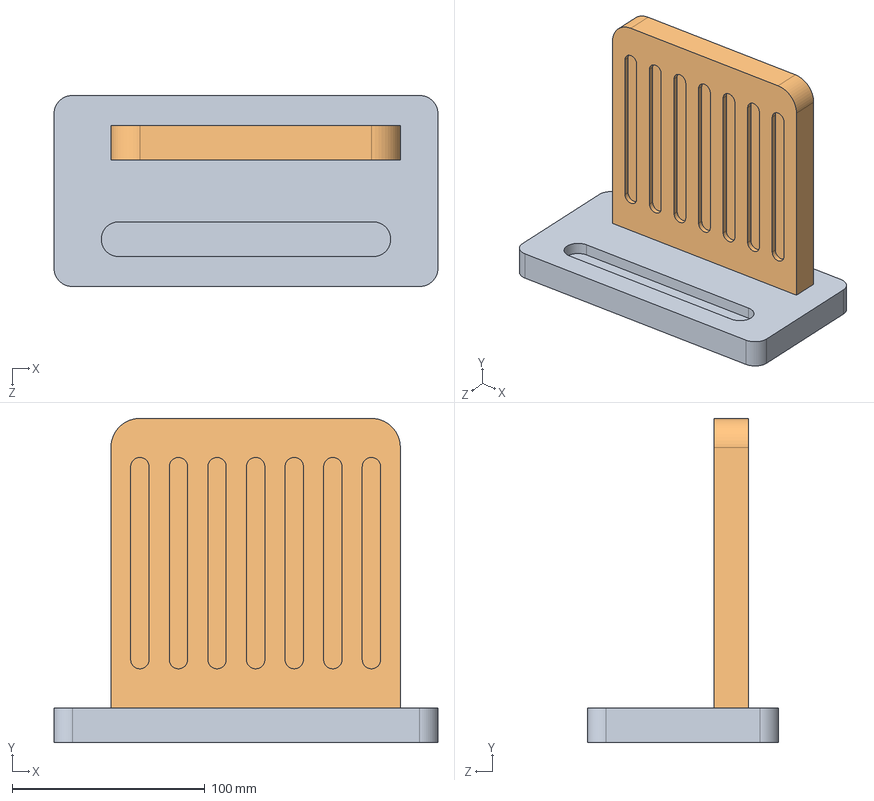
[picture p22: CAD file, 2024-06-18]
labs/experimental/F0617_TableInsert_StandAsm1.STEP
199.0 x 168.0 x 99.0 mm
F0617_TableInsert_StandBase200x100
F0617_TableInsert_StandBack

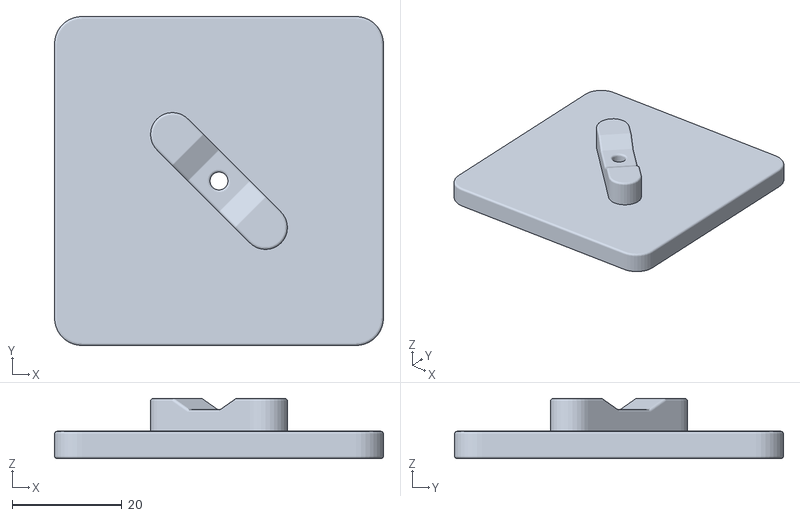
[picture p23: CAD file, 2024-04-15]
labs/experimental/Drawer Front XLatch Base Assembly (1).stl
60.0 x 60.0 x 11.0

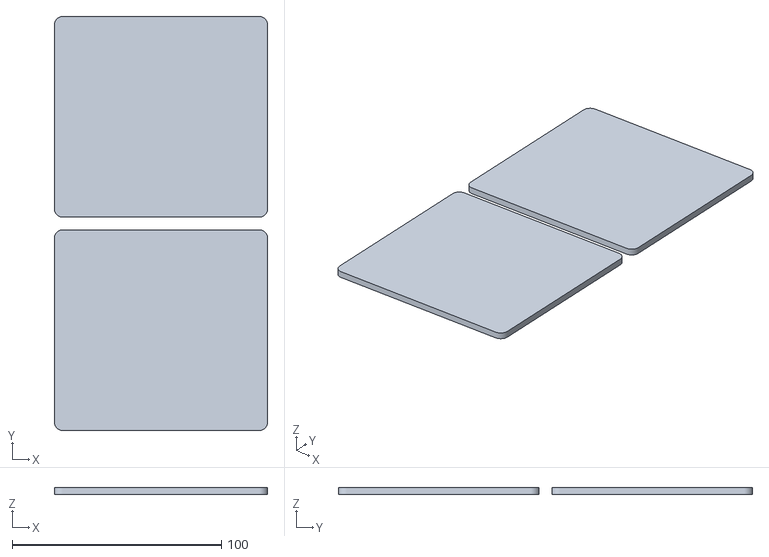
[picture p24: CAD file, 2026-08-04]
designs/art_plates/models/AP102-2x18inch.stl
102.0 x 198.0 x 3.20

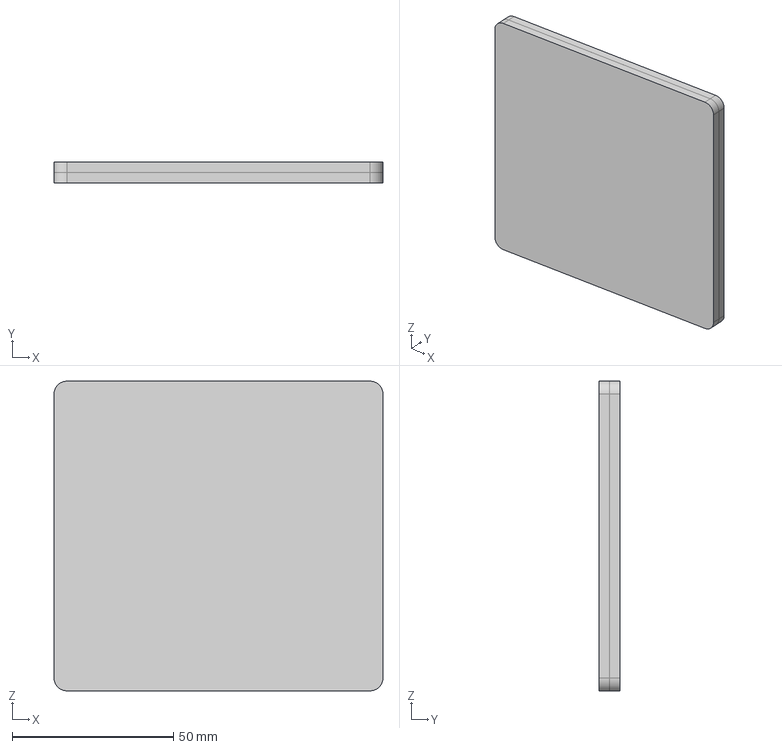
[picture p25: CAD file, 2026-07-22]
designs/art_plates/modx-ap102-short.step
102.0 x 6.40 x 96.0 mm

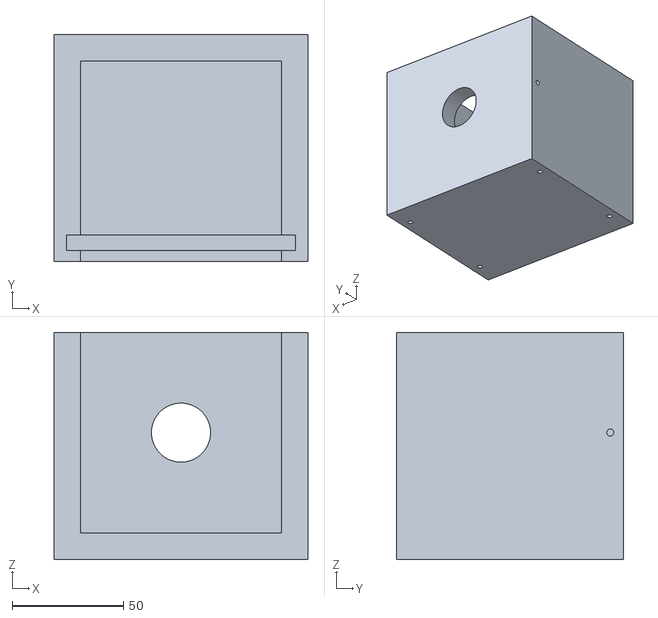
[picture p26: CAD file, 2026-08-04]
designs/mod_block/models/MB1-1body.stl
114.0 x 102.0 x 102.0

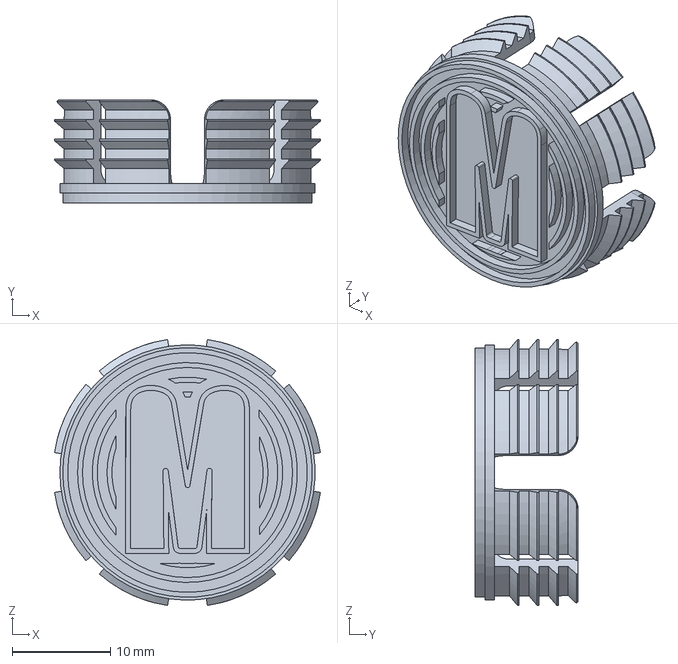
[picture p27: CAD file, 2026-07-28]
designs/mod_plug/models/modplug_MP1-XAH_3a.step
27.1 x 10.5 x 27.1 mm

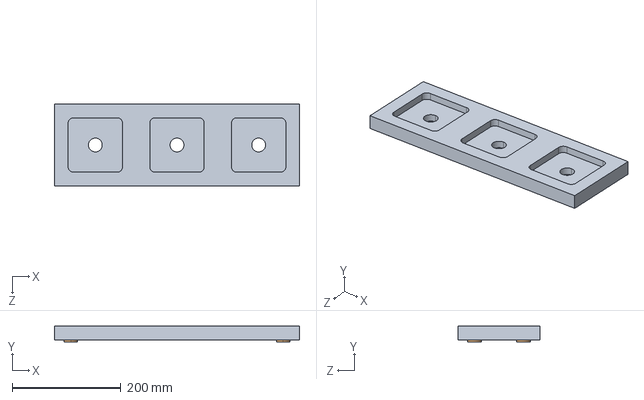
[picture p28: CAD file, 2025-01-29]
labs/experimental/T0129_3Base_1a.STEP
450.0 x 28.6 x 150.0 mm

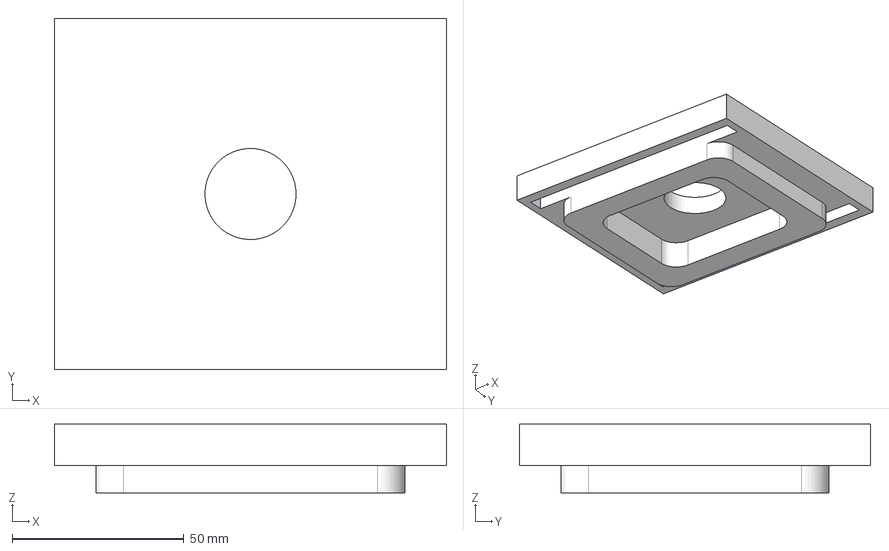
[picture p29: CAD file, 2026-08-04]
designs/mod_block/models/MB1-cap.step
114.0 x 102.0 x 20.0 mm

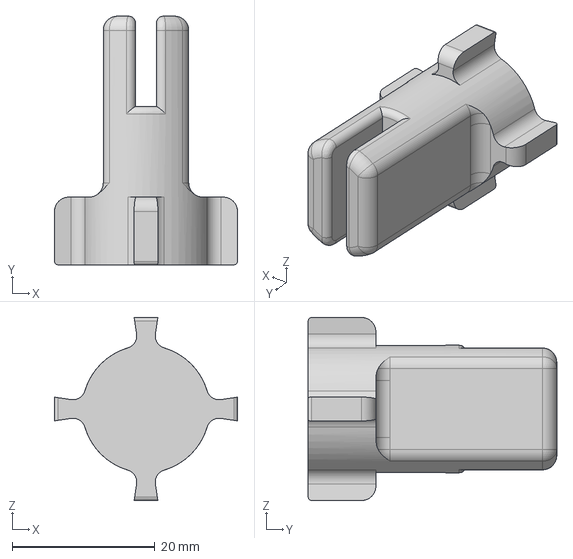
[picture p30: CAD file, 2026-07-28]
designs/mod_plug/models/modplug_key.step
25.7 x 34.9 x 25.7 mm

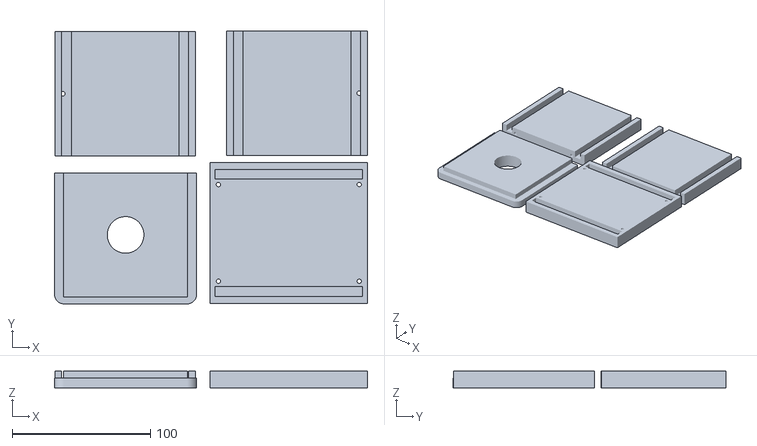
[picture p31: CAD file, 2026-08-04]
designs/mod_block/models/MB1-multibody.stl
226.7 x 197.7 x 12.0

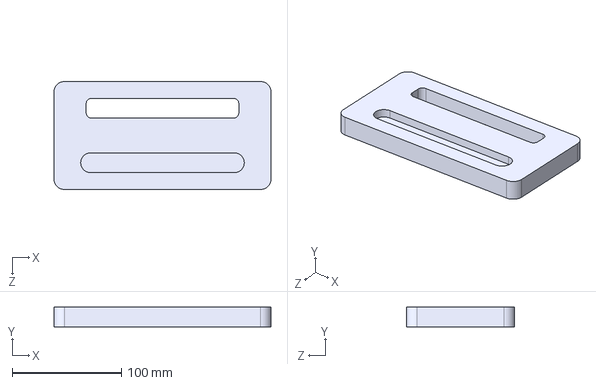
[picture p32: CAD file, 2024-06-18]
labs/experimental/F0617_TableInsert_StandBase200x100.STEP
199.0 x 18.0 x 99.0 mm

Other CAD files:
designs/art_plates/models/AP102-14inch.step
designs/mod_block/models/MB1-body.step
labs/experimental/F0617_TableInsert_StandBack.STEP
labs/experimental/F0529_Span100_Wood_C2.STL
designs/art_plates/models/AP102-14inch.stl
designs/art_plates/modx-ap102-short.dxf
designs/mod_block/models/MB1-cap.stl
labs/experimental/Aligner v1.stl
labs/experimental/CabFrame Bar2.stl
labs/experimental/CabFrame Corner2 (1).stl
labs/experimental/Drawer Front XLatch Test Wall 1 (1).stl
labs/experimental/Drawer Front XLatch Top (1).stl
labs/experimental/F0529_Post80_Wood_C.STL
labs/experimental/F0529_PostPlug_C.STL
labs/experimental/Furn1 v8.stl
labs/experimental/Furn2 v6 bamboo front only.3mf
labs/experimental/Furn2 v6.stl
labs/experimental/Furn3 v18.stl
labs/experimental/Furn3 v20.stl
labs/experimental/Furn3 v21.stl
labs/experimental/Furn3 v3.step
labs/experimental/Furn3 v3.stl
labs/experimental/Furn3 v8.stl
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

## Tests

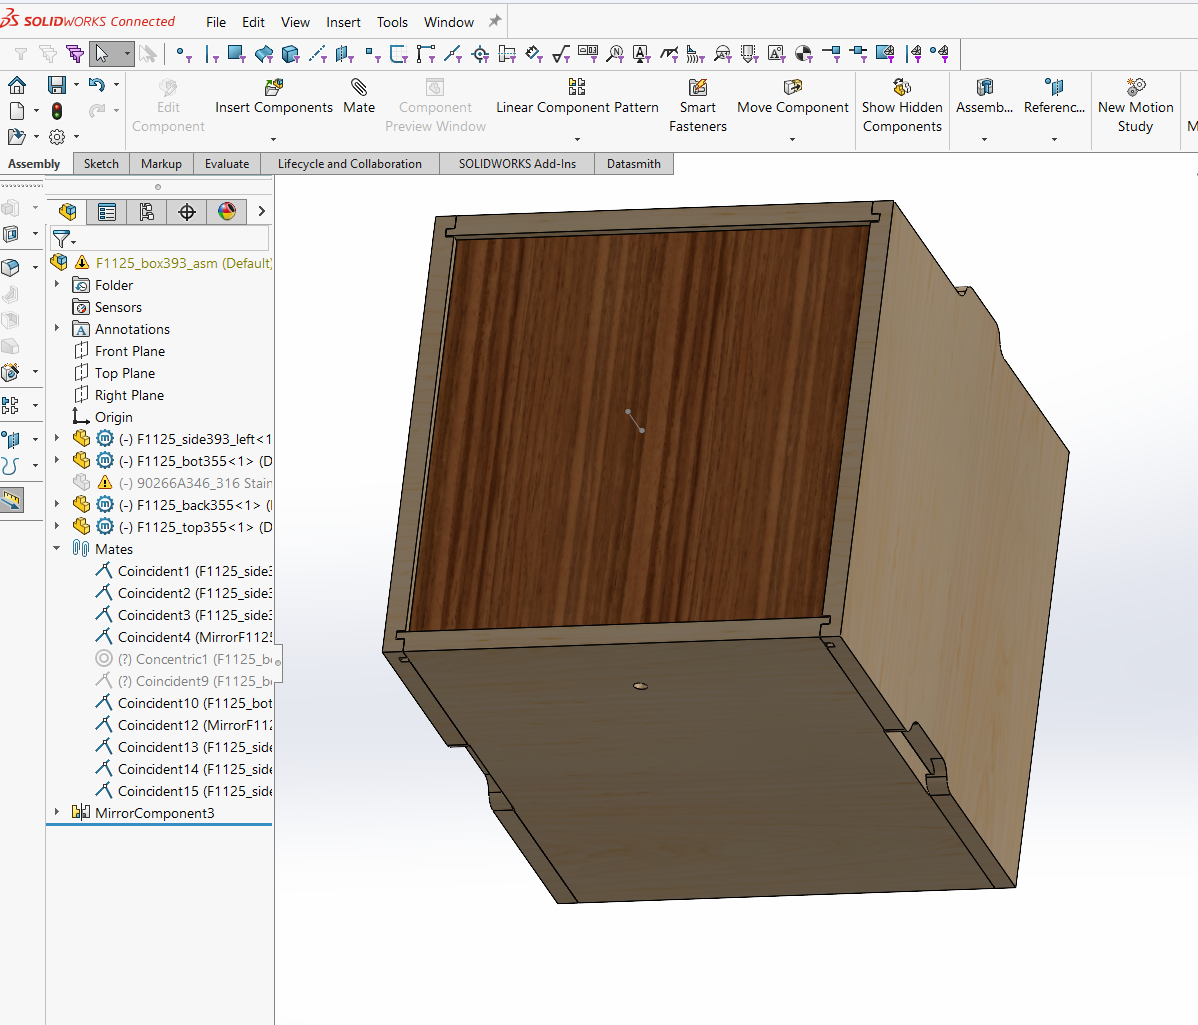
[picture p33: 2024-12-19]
labs/experimental/F1125_393BoxBack.png

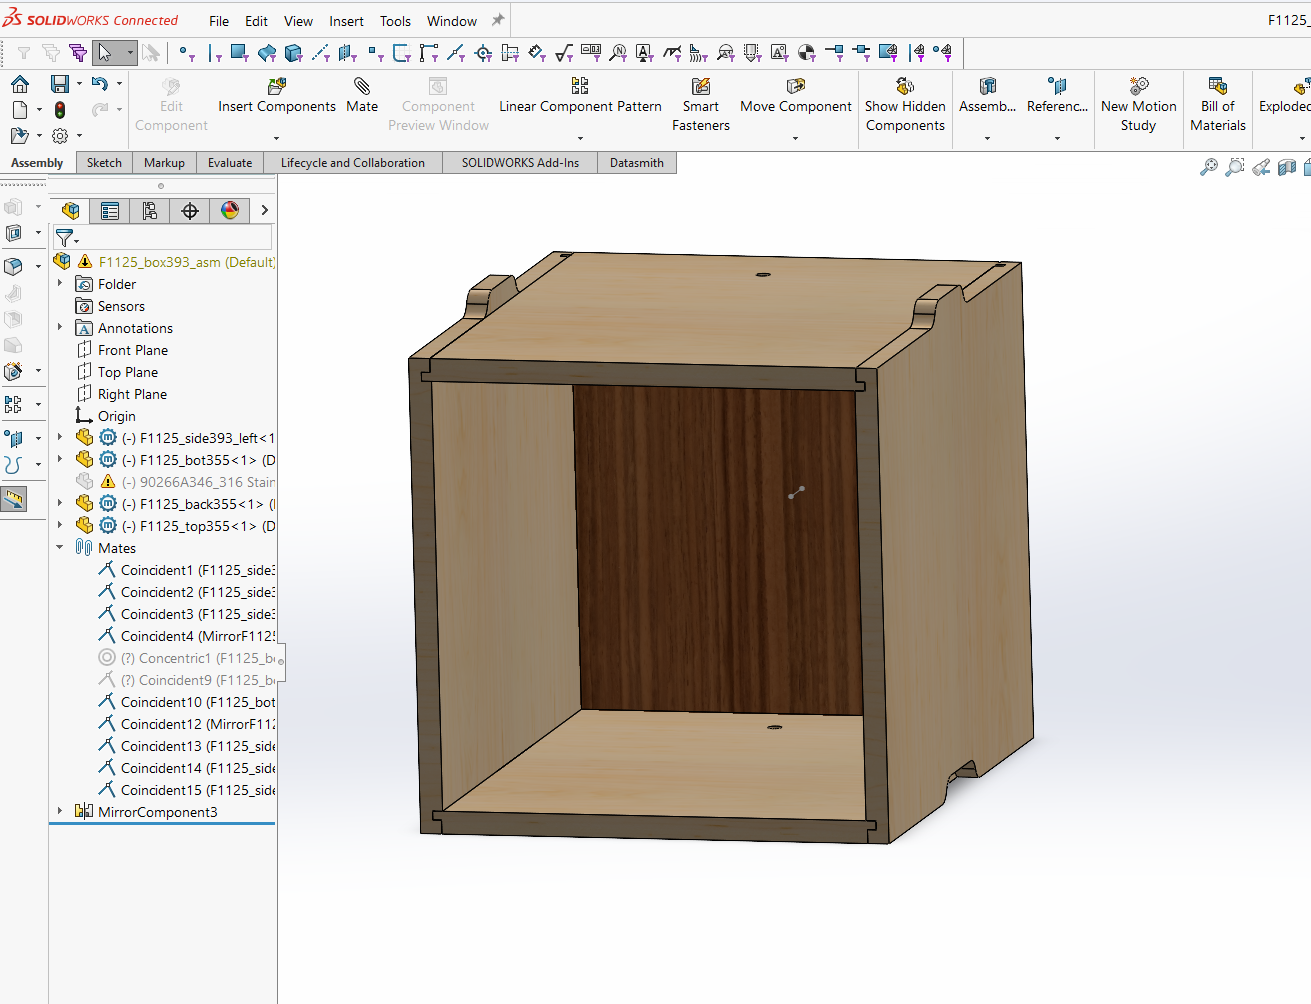
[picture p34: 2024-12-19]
labs/experimental/F1125_393BoxFront.png

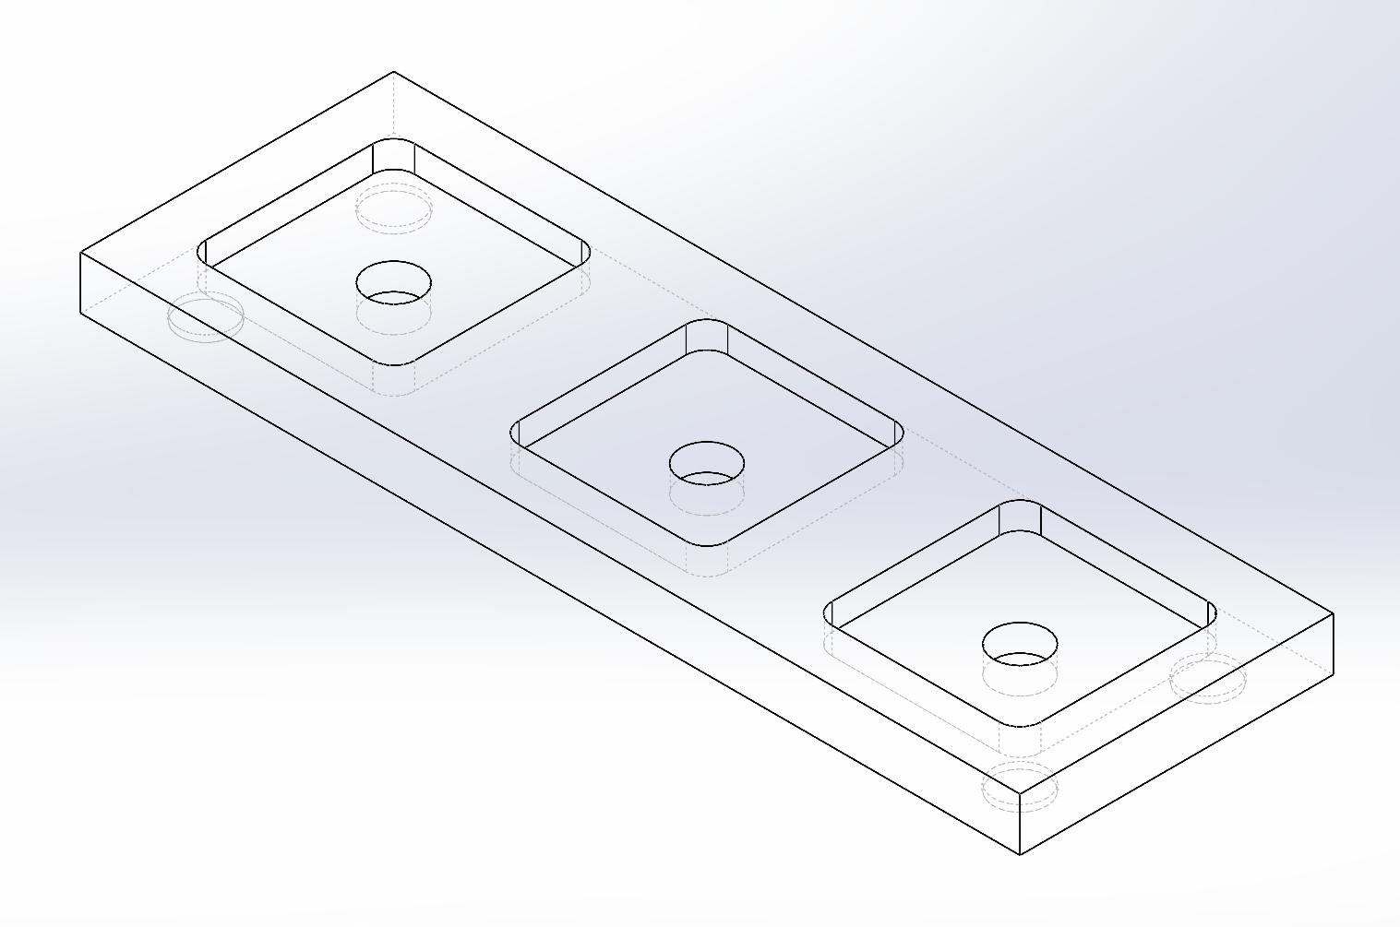
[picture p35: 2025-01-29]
labs/experimental/T0129_3BaseWire.png

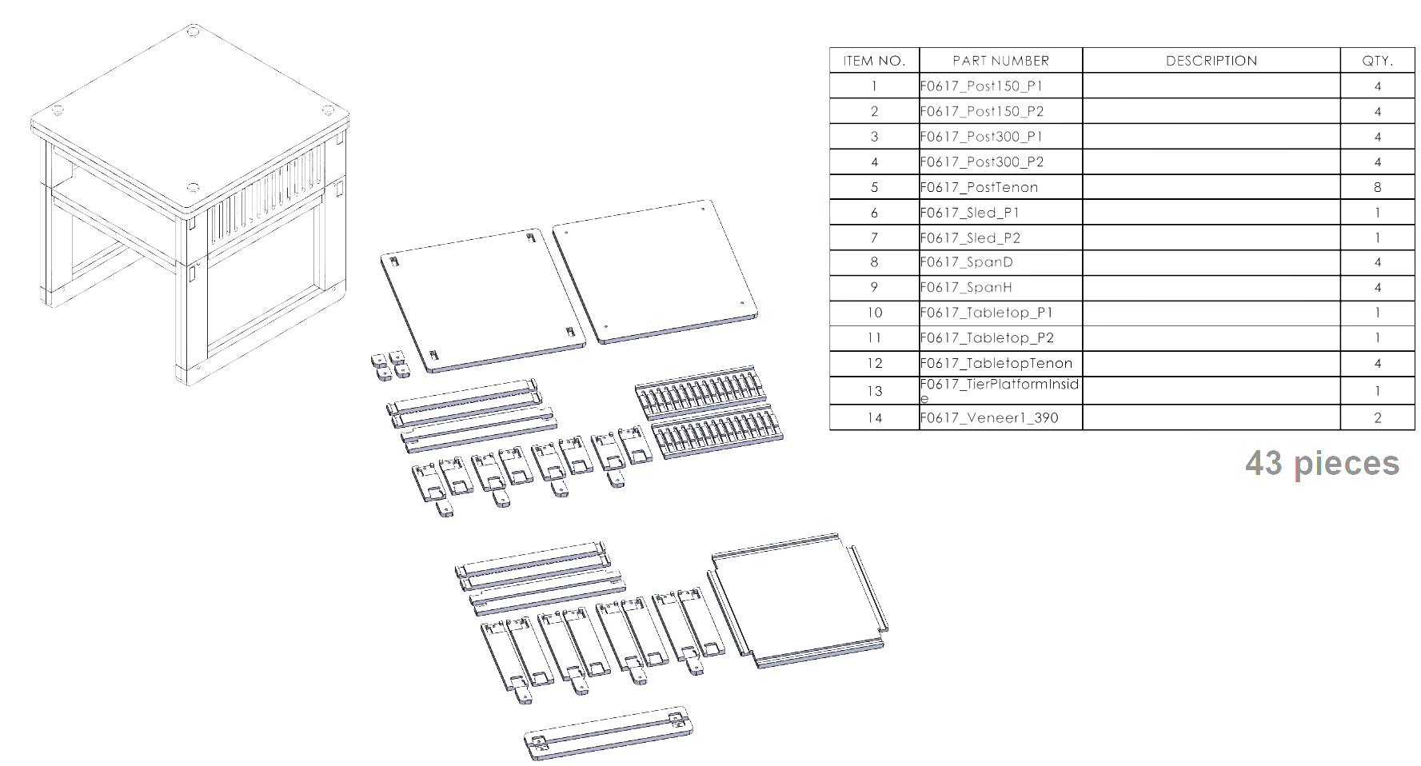
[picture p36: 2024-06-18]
labs/experimental/F0617_Screenshot_TestLayout.png

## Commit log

2024-03-24 chore: Organize files in folders, add LICENSE file, update README with rationale, set up config, add initial content
    [Aligner v1.stl, Furn1 v8.stl, Furn2 v6 bamboo front only.3mf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]
2024-03-26 feat: Add latest prototypes
    [FurnNightst02a v5.stl, Pulls1 v5.f3d, Pulls1 v6.3mf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]
2024-04-02 chore: add placeholder for connectors
2024-04-15 feat: more iterations of designs
    [CabFrame Bar2.stl, CabFrame Corner2 (1).stl, Drawer Front XLatch Base Assembly (1).stl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]
2024-05-30 feat: new F0529 prototypes
    [F0529_Post80_Wood_C.STL, F0529_PostPlug_C.STL, F0529_Span100_Wood_C2.STL]
2024-06-18 feat: Add more test layouts
    [F0617_TableInsert_StandAsm1.STEP, F0617_TableInsert_StandBack.STEP, F0617_TableInsert_StandBase200x100.STEP]
2024-07-18 feat: New prototypes
2024-12-19 Adding F1125 versions with a preview of a larger integration.
    [F1125_box143_asm.STEP, F1125_box268_asm.STEP, F1125_box393_asm.STEP]
2025-01-29 Adding T0129 3Base as STEP
    [T0129_3Base_1a.STEP]
2025-01-29 Adding T0129 3Base as STL
    [T0129_3Base_1a.STL]
2025-08-14 Adding B384 prototypes
2026-07-22 Adding Art Plates AP102 specifications and examples.
    [modx-ap102-short.dxf, modx-ap102-short.step]
2026-07-28 Adding documentation for art_plates, mod_block, mod_plug. Updating naming, principles.
    [modplug_MP1-XAH_3a.step, modplug_key.step]
2026-08-04 Improving documentation, adding models
    [AP102-14inch.step, AP102-14inch.stl, AP102-2x18inch.stl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]
